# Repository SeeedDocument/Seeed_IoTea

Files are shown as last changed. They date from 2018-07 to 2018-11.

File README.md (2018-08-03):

# Seeed_IoTea

IoTea的节点代码和PCB图。
<a href="https://cn1.loriot.io/apps/websocket.html?token=vnwDBQAAAA1jbjEubG9yaW90LmlvliKTqUfFMlIiSug0jy9a2A==">点我查看原始数据。</a>

## 主要器材清单

### 网关

- <a href="https://www.seeedstudio.com/LoRa-LoRaWAN-Gateway-868MHz-Kit-with-Raspberry-Pi-3-p-2823.html">LoRa LoRaWAN Gateway - 868MHz Kit with Raspberry Pi 3</a>
- <a href="https://www.seeedstudio.com/Raspberry-Pi-Ultimate-Cooling-Dual-Fan-p-2926.html">Raspberry Pi Ultimate Cooling Dual Fan</a>

### 节点

- <a href="https://www.seeedstudio.com/s/Seeeduino-LoRaWAN-p-2780.html">Seeeduino LoRaWAN</a>
- <a href="https://www.seeedstudio.com/s/Grove-Temp%26Humi%26Barometer-Sensor-(BME280)-p-2653.html">BME 280 空气温湿度传感器</a>
- <a href="https://www.seeedstudio.com/s/Grove-Dust-Sensor%EF%BC%88PPD42NS%EF%BC%89-p-1050.html">Dust sensor</a>
- <a href="https://www.seeedstudio.com/s/Grove-Carbon-Dioxide-Sensor(MH-Z16)-p-1863.html">CO2 sensor</a>
- <a href="https://www.seeedstudio.com/s/Grove-Oxygen-Sensor(ME2-O2-%D0%A420)-p-1541.html">O2 sensor</a>
- <a href="https://www.seeedstudio.com/s/Grove-Digital-Light-Sensor-p-1281.html">Digital Light Sensor</a>
- <a href="https://www.seeedstudio.com/s/Soil-Moisture-%26-Temperature-Sensor-p-1356.html">Soil Moisture & Temperature Sensor</a>

# 代码部分：
## 1. 数据格式

节点向网关上传的数据为：

```c
unsigned char Lora_data[15] = {0,1,2,3,,4,5,6,7,8,9,10,11,12,13,14};
```

各项数据含义：

- **Lora_data[0]**：空气温度，摄氏度
- **Lora_data[1]**：空气湿度，百分比
- **Lora_data[2]**：海拔高度高8位，米
- **Lora_data[3]**：海拔高度低8位
- **Lora_data[4]**：CO2浓度高8位
- **Lora_data[5]**：CO2浓度低8位
- **Lora_data[6]**：灰尘浓度高8位
- **Lora_data[7]**：灰尘浓度低8位
- **Lora_data[8]**：光照强度高8位
- **Lora_data[9]**：光照强度低8位
- **Lora_data[10]**：氧气含量，单位为千分之一
- **Lora_data[11]**：土壤温度，摄氏度
- **Lora_data[12]**：土壤湿度，百分比
- **Lora_data[13]**：电池电压，单位为0.1V
- **Lora_data[14]**：错误代码

错误代码含义：

```
Lora_data[14] = [bit7, bit6, bit5, bit4, bit3, bit2, bit1, bit0]
```
- bit0：1 为 BME 280 空气温湿度传感器错误
- bit1：1 为 CO2 传感器错误
- bit2：1 为灰尘传感器错误
- bit3：1 为 Digital Light Sensor 错误
- bit4：1 为氧气传感器数据错误
- bit5：1 为土壤温湿度传感器错误
- bit6：保留
- bit7：保留

另外本文件夹内有错误代码转换器：Error_code_transform.exe ，可以打开这个.exe文件并输入十六进制的错误代码，然后就得到了传感器错误类型。

## 2. 参数调节

### 1. 数据发送运行周期

```c
// seeedtea.ino
#define interval_time 600			//间隔时间，秒
```
更改此参数可改变数据发送间隔。在每次循环中，数据采集需耗时约 1 分钟，不建议将此值改为60秒以内。值越大，系统运行越省电。

### 2. 灰尘传感器预热时间

```c
// seeedtea.ino
#define Preheat_time 30000			//Dust Sensor预热时间，单位 ms
//Dust_other.cpp
#define sampletime_ms 30000		//采样时间30s;
```
灰尘传感器需要一定预热时间来让传感器内的空气流动起来。

### 3. 电压系数

```c
//POWER_Ctrl.cpp
#define Battery_coefficient 0.159864	//ADC读数乘以这个系数就是电池电压
#define Solar_coefficient   0.22559	  //ADC读数乘以这个系数就是太阳能电压
```

### 4. 风扇参数调节

```c
//POWER_Ctrl.cpp
#define Fan_start_temp 45     //风扇开始运行温度
#define Fan_start_light 500   //风扇开始运行光照强度
```

### 5. 氧气传感器参数

```c
//Oxygen.cpp
#define O2_percentage 208.00  //初始化时会按照这个值校准氧气传感器，单位为千分之一
```

### 6. 宏开关，注释后会停止相应模块工作

```c
// seeedtea.ino
#define LORA_RUN      //注释后lora初始化和数据发送停止
#define SENSOR_RUN    //注释后外部传感器停止工作

//POWER_Ctrl.cpp
#define FAN_ON        //使用一个固定的电池电压代替采集到的电池电压，解除电压对风扇的判断
                      //测试使用。实际应用需注释掉
/******* DS18B20 模式控制 **********************/
#define Slower_Mode		//慢速模式获取温度。注释掉即为快速模式
```

### 7. 引脚定义

D2：接 LED 指示灯和外部复位单片机

I2C：SCL 和 SDA

```c
//Dust_other.h
#define Dust_pin 3

//CO2.cpp
#define CO2_serial Serial1    //CO2 传感器使用D0和D1硬件串口

//seeedtea.ino
#define dataPin 6   //土壤水分和温度传感器数据引脚
#define clockPin 7  //土壤水分和温度传感器时钟引脚

//POWER_Ctrl.h
#define DS18B20_pin 8   //板载温度传感器
#define Fan_pin 9       //风扇引脚
#define Air_CtrlPin 10  //空气传感器控制引脚
#define Soil_CtrlPin 11 //土壤传感器控制引脚
#define Battery_pin A2  //电池电压采集引脚
#define Solar_pin A3    //太阳能电压采集引脚

//Oxygen.h
#define O2_pin A1
```

### 8. 看门狗定时器

看门狗定时器用于监测系统运行状态，当系统运行异常时会复位单片机，从而使其可以长期不间断运行。

需要引用的库：

- Adafruit_SleepyDog.h            已经添加进项目中
- Adafruit_ASFcore-master.zip     打包放在项目文件夹中，需要手动添加进Arduino IDE中

#### 相关函数：

##### 1. 使能看门狗

```c
int WatchdogSAMD::enable(int maxPeriodMS, bool isForSleep)
```
输入参数：
- int maxPeriodMS：等待时间，单位毫秒。超时会复位。最大允许16000毫秒。

返回值：
- int类型，返回实际等待时间

##### 2. 复位看门狗

```c
void WatchdogSAMD::reset()
```

输入参数：无

输出参数：无

调用该函数来复位看门狗定时器，简称“喂狗”。超出等待时间未复位就会使单片机重启。

##### 3. 停止看门狗

```c
void WatchdogSAMD::disable()
```

停止看门狗定时器。

## 3. 传感器详细信息

### 1.	Temp&Humi&Barometer Sensor

供电：5Vor3.3V

参数范围：温度-40-85℃ 湿度0%-100% 气压300-100hPa

IIC通信，地址0X76，

相关函数：bme280.getTemperature(), bme280.getHumidity(), bme280.getPressure()

Lora_data[0]： 温度 Lora_data[1]： 湿度

Lora_data[2]：高8位Lora_data[3]：低8位 气压

### 2.	Dust Sensor（PPD42NS）

供电：5V 单位：pcs/L或pcs/0.01cf

相关函数：Dust_value = Dust_concentration()

Lora_data[6]：高8位  Lora_data[7]：低8位 灰尘

### 3.	Carbon Dioxide Sensor(MH-Z16)

供电：4.5V-6V 范围：0-2000ppm

UART通信

相关函数：unsigned int CO2_dataRecieve(void)

Lora_data[4]：高8位   Lora_data[5]：低8位  CO2浓度

### 4.	Digital Light Sensor

供电：5V 范围0.1-40000LUX

IIC通信，地址 0X29,

相关函数：TSL2561.readVisibleLux()

Lora_data[8]：高8位   Lora_data[9]：低8位  光照

### 5.	Oxygen Sensor(ME2-O2-Ф20)

供电：3.3V/5V 范围：0-25%

读模拟值

int O2_value()

Lora_data[10] 氧气浓度（通过该函数获得的值要除以10，得到百分比）

### 6.	Soil Moisture & Temperature Sensor

供电：3.3V 范围：温度-40-+123.8℃ 湿度0-100%

sht1x.readTemperatureC() sht1x.readTemperatureF() sht1x.readHumidity()

Lora_data[11] 土壤温度 Lora_data[12] 土壤湿度

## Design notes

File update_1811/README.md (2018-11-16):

# Seeed IoTea LoRa Solution

*Internet+* is a popular concept at this moment. This time we tried the Internet plus agriculture to make tea garden grows out the Internet Tea.

## Things used in this project

### Hardware components

- LoRa/LoRaWAN Gateway Kit
- Grove - Barometer Sensor(BME280)
- Grove - Dust Sensor
- Grove - Gas Sensor(O₂)
- Grove - CO2 Sensor
- Grove - Digital Light Sensor
- Soil Moisture & Temperature Sensor
- USB Camera
 
### Software apps and online services

- Microsoft Visual Studio 2015

## Story

On Mengding Mountain northeast of Ya’an, Sichuan, the mountain ridge runs west to east in a sea of green. This is a most familiar sight for 36-year-old Deng, one of the very few Mengding tea makers of his generation, with a plantation of 50mu (=3.3 hectares) situated at 1100m above sea level. Deng comes from a family of tea makers, but carrying on the family legacy is not an easy task. “Our teas are grown at high altitude in an organic environment to ensure its excellent quality. But at the same time, the growth density is low, cost is high and budding is uneven, making tea hard to harvest. That’s why high-mountain teas are normally small harvests and their values are not reflected on the market.”For the past two years, Deng has been trying to raise consumer awareness of high-mountain tea to promote their value. And when he met Fan, who was looking for a plantation to implement Seeed’s IoTea technology, a perfect match for a solution was made.

### Hardware Connection

The hardware of this project can be splitted to 4 parts: Power, Sensors, Node and Gateway. Following article will show you how to complete it step by step.

**Power Part**

Power Part mainly contains a Solar Panel and a Lithium Battery, if you just build this project for demonstration, you can ignore them. Or you can follow [Previous tutorial](https://project.seeedstudio.com/SeeedStudio/seeed-lora-iotea-solution-b5ee95) to install node power.

**Sensor Part**

In Sensor Part, because of the many of sensors, we used a weather station, and also made a Acrylic bracket to install them.

Sensor Part

As you see in the picture above, Digital Light Sensor always on the top, so that it can collect lighting infomation. The sensors that will generate heat are installed in middle of the Acrylic bracket, such as O2 Sensor, Dust Sensor and CO2 Sensor. At last, Temperature and Humidity Sensor on the bottom of Acrylic bracket.

Besides, Soil Temperature and Humidity Sensor is installed alone in the soil.

**Node Part**

Node Part

Node Part is a Seeeduino LoRaWan which installed in a Waterproof Box, it connect to power and sensors via Water Joints. Among them, Dust Sensor connect to LoRaWan's digital pin D3, CO2 Sensor connect to pin D4 & D5, Soil Sensor connect to pin D6 & D7, O2 Sensor connect to analog pin A1 and Light Sensor & Barometer Sensor connect to I2C port.

*NOTE: A 10k Resistor should be added between Soil Sensor's Blue(Data) cable and Red(Vcc) cable.*

Seeeduino LoRaWan collect sensors value once in a while, and send them to Gateway via LoRa. The data format like below:

    {
    	[0],	/* Air tempreature(℃)						*/
    	[1],	/* Air humidity(%)							*/
    	[2],	/* Altitude(m) high byte					*/
    	[3],	/* Altitude(m) low byte						*/
    	[4],	/* CO2 concentration(PPM) high byte			*/
    	[5],	/* CO2 concentration(PPM) low byte			*/
    	[6],	/* Dust concentration(pcs/0.01cf) high byte	*/
    	[7],	/* Dust concentration(pcs/0.01cf) low byte	*/
    	[8],	/* Light intensity(lux) high byte			*/
    	[9],	/* Light intensity(lux) low byte			*/
    	[10],	/* O2 concentration(%)						*/
    	[11],	/* Soil temperature(℃)						*/
    	[12],	/* Soil humidity(%)							*/
    	[13],	/* Battery voltage(V)						*/
    	[14]	/* Sensor error code						*/
    }

Each bit in Sensor Error Code byte has a difference meaning, just like below:

    {
    	bit0: 1;		/* Barometer Sensor Error			*/
    	bit1: 1;		/* CO2 Sensor Error					*/
		bit2: 1;		/* Dust Sensor Error				*/
		bit3: 1;		/* Light Sensor Error				*/
		bit4: 1;		/* O2 Sensor Error					*/
		bit5: 1;		/* Soil Sensor Error				*/
		reserved: 2;	/* Reserved							*/
    }

**Gateway Part**

Gateway Part

Gateway Part is a Raspberry Pi which plugged Gateway module RHF0M301–868 and PRI 2 Bridge RHF4T002, it installed in a Waterproof Box and connect to power & USB Camera via Water Joints. Because it use specialized firmware, please follow [Seeed Wiki](http://wiki.seeedstudio.com/LoRa_LoRaWan_Gateway_Kit/) to configure it.

### Software Programming

As Hardware Connection, Software Programming also can be splitted, it can be splitted to 3 parts: Node, Gateway and Website.

**Node Part**

Most of drivers that Node Part required are already contained in `origin_driver` folder. The libraries following down need to be installed manually: 

- [Adafruit_ASFcore](https://github.com/adafruit/Adafruit_ASFcore)

Because the project is complicated, we recommend you use Microsoft Visual Studio instead of Arduino IDE. A plugin called Visual Micro can help you biuld an Arduino project by using Visual Studio, click [here](https://www.visualmicro.com/) for more information.

For better readability and maintainability, we use Object-Oriented Programming this time. The class diagram of this project looks like below:

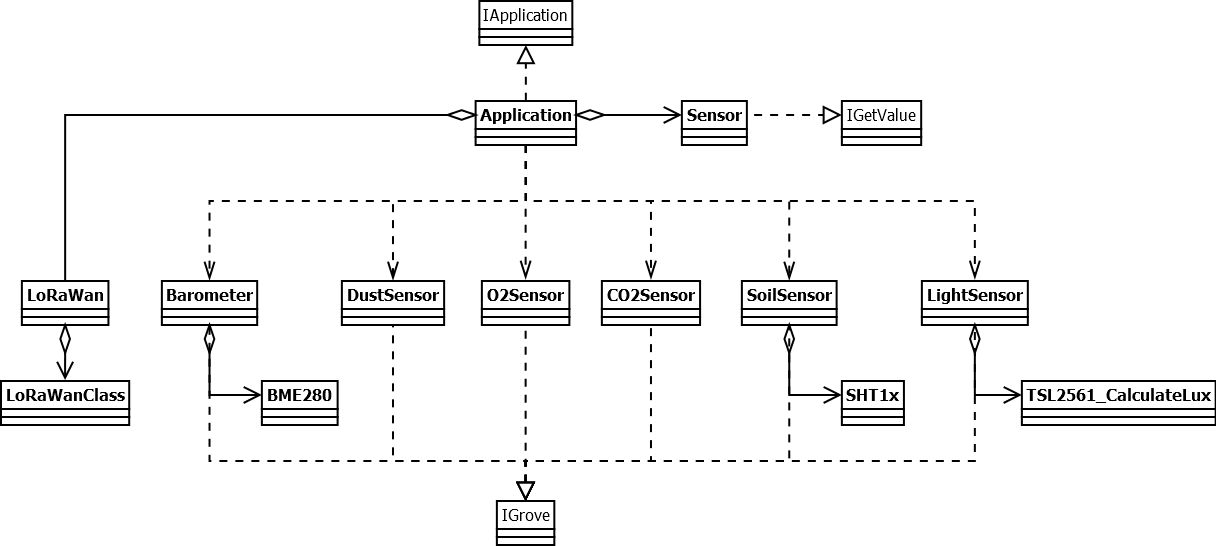
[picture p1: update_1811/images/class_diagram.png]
class diagram


For those sensors already have OOP driver, we repacked it to adapt this project, for others, we rewrote their drivers by using OOP. The Sensor class in middleware layer is used to unify interfaces of real sensors, for example, a barometer sensor can collect temperature, humidity and altitude at the same time, so it has 3 interfaces to acquire temperature, humidity and altitude. But they have difference method name, which will make the program of acquiring sensors value more complicated, just like this:

    barometer->getTemperature();
    barometer->getHumidity();
    barometer->getAltitude();
    // ...
    another_sensor->getSomeValue();
    // ...

But using OOP, it looks like this:

    for (auto i = 0; i < SENSORS_COUNT; i++) {
    	sensors[i]->getValue();
    }

We also packed an Application class, it implement IApplication interface, the setup() and loop() method in IoTea.ino can call setup() and loop() method in Application object.

*NOTE: USB Serial is used to debug ONLY. After debugging, please comment it's initialize code in setup() method.*

**Gateway Part**

Gateway Part's Python program in home folder is used to take photos and upload them to Amazon S3 Server every hour. Before you use it, configure your AWS by following steps. Firstly, install AWS SDK and AWS CLI to gateway by using commands: 

	pip install boto3
    pip install awscli --upgrade --user

And then, enter AWS CLI install folder and run AWS CLI:

    cd ~/.local/bin && ./aws configure

Configure your AWS Access Key ID, AWS Secret Access ID and Default region name. After that, you are ready to take and upload photos to AWS S3 Server, photo.py looks like:

    #!/usr/bin/python
    
    import boto3
    import os
    import time
    
    # Create an S3 client
    s3 = boto3.client('s3')
    bucket_name = 'static.seeed.cc'
    
    while True:
    	try:
    		localtime = time.localtime(time.time())
    		if int(time.strftime('%M', localtime)) != 0:
    			continue
    		
    		year = time.strftime('%Y', localtime)
    		season = int(time.strftime('%m', localtime)) % 4 + 1
    		filename = time.strftime('%Y%m%d-%H0000', localtime) + '.jpg'
    		
    		# Take photo
    		os.system("fswebcam --no-banner -r 1920x1080 {}".format(filename))
    		
    		upload_path = 'files/iotea/{}s{}/{}'.format(year, season, filename)
    		
    		# Uploads the given file using a managed uploader, which will split up large
    		# files automatically and upload parts in parallel.
    		s3.upload_file(filename, bucket_name, upload_path)
    		print('Uploaded file to {}'.format(upload_path))
    		
    		# Remove local file
    		os.remove(filename)
    		print('Deleted local file {}'.format(filename))
    	except:
    		continue
    	finally:
    		time.sleep(60)

If you don't like to upload your photos, you can comment codes about S3 above. For run this program after booting gateway every time, you can install a Desktop to your Raspberry Pi by using these commands:

    sudo apt-get update
    sudo apt-get install xorg
    sudo apt-get install lxde openbox
    sudo apt-get install pix-icons pix-plym-splash pixel-wallpaper
    sudo apt-get install raspberrypi-ui-mods
    sudo reboot

And then, add `@lxterminal -e python /home/rxhf/photo.py` to file `/home/rxhf/.config/lxsession/LXDE-pi`, let it looks like this:

    @lxpanel --profile LXDE-pi
    @pcmanfm --desktop --profile LXDE-pi
    @lxterminal -e python /home/rxhf/photo.py
    @xscreensaver -no-splash
    @point-rpi

**Website**

You can configure a web site by following [here](https://github.com/SeeedDocument/iotea-hb/blob/master/iotea.md), or using other framework.

## Operation

You can visit our websites to view real-time data:

- [In Yaan](https://iotea.seeed.cc/)
- [Demonstration](https://iotea-hb.seeed.cc/)

[Video](https://www.youtube.com/watch?v=4df5kaaKa6I&feature=youtu.be)

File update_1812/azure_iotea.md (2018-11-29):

# Seeed IoTea LoRa Solution (with Azure, Update 1812)

Microsoft Azure is a Cloud Service which provide more powerful and stable computing power, this time we tired send our IoTea data to it.

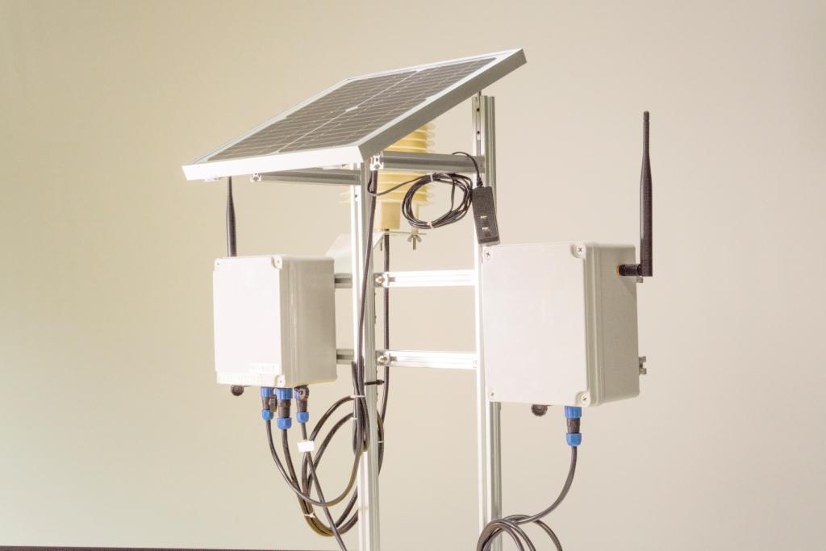
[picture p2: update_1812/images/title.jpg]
Title


## Things used in this project
### Hardware components
- Seeed LoRa LoRaWAN Gateway - 868MHz Kit with Raspberry Pi 3
- Seeed Grove - Temp&Humi&Barometer Sensor (BME280)
- Seeed Grove - Dust Sensor（PPD42NS）
- Seeed Grove - Oxygen Sensor(ME2-O2-Ф20)
- Seeed Grove - Carbon Dioxide Sensor(MH-Z16)
- Seeed Grove - Digital Light Sensor
- Seeed Soil Moisture & Temperature Sensor
- USB Camera
### Software apps and online services
- Microsoft Visual Studio 2015
- Microsoft Azure

## Story
On Mengding Mountain northeast of Ya’an, Sichuan, the mountain ridge runs west to east in a sea of green. This is a most familiar sight for 36-year-old Deng, one of the very few Mengding tea makers of his generation, with a plantation of 50mu (=3.3 hectares) situated at 1100m above sea level. Deng comes from a family of tea makers, but carrying on the family legacy is not an easy task. “Our teas are grown at high altitude in an organic environment to ensure its excellent quality. But at the same time, the growth density is low, cost is high and budding is uneven, making tea hard to harvest. That’s why high-mountain teas are normally small harvests and their values are not reflected on the market.”For the past two years, Deng has been trying to raise consumer awareness of high-mountain tea to promote their value. And when he met Fan, who was looking for a plantation to implement Seeed’s IoTea technology, a perfect match for a solution was made.

### Hardware Connection
Please follow [Previous Tutorial](https://project.seeedstudio.com/SeeedStudio/seeed-iotea-lora-solution-update-1811-860035) to connect your hardware.

### Cloud Configure
**Step 1. Create Resource Group**

Click [here](https://portal.azure.com) to login Microsoft Azure. And then, enter Resource groups in list on the left of dashboard, click Add to add a Resource Group.

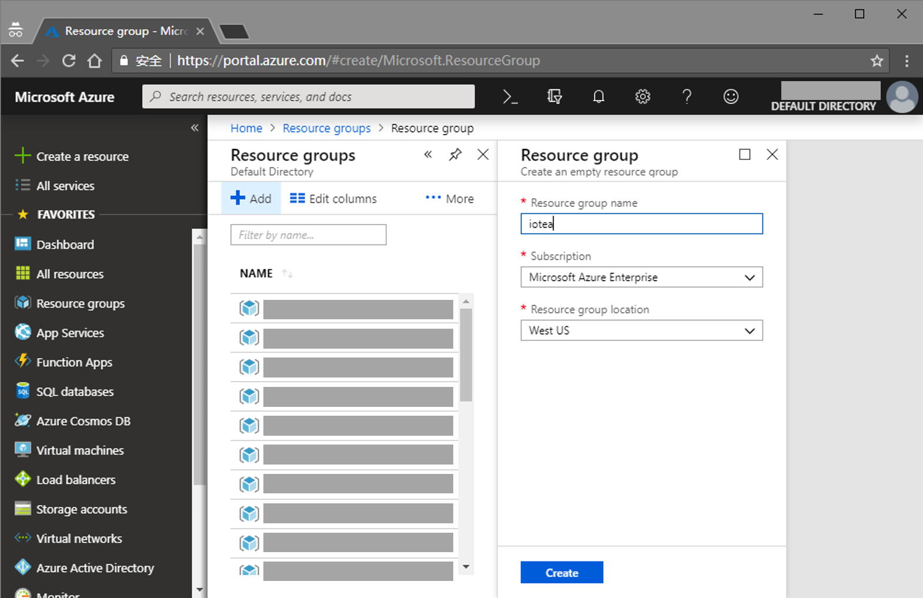
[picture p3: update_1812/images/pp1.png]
Add Resource Group


A Resource Group is used to manage all resources in project, after using cloud resources, delete resource group to delete all resources to avoid charges. In opened page, fill Resource group name(such as iotea), choose Subscription and Resource group location if needed, click Create to create a Resource Group. 

**Step 2. Create Iot Hub**

Now you can create a cloud resource, click Create a resouce on the left, choose Internet of Things - Iot Hub, it will open a new page.

In Basics tab, choose the Resource Group you just created, and fill Iot Hub Name(such as iotea), choose Subscription and Region if needed, and then turn to Size and scle tab.

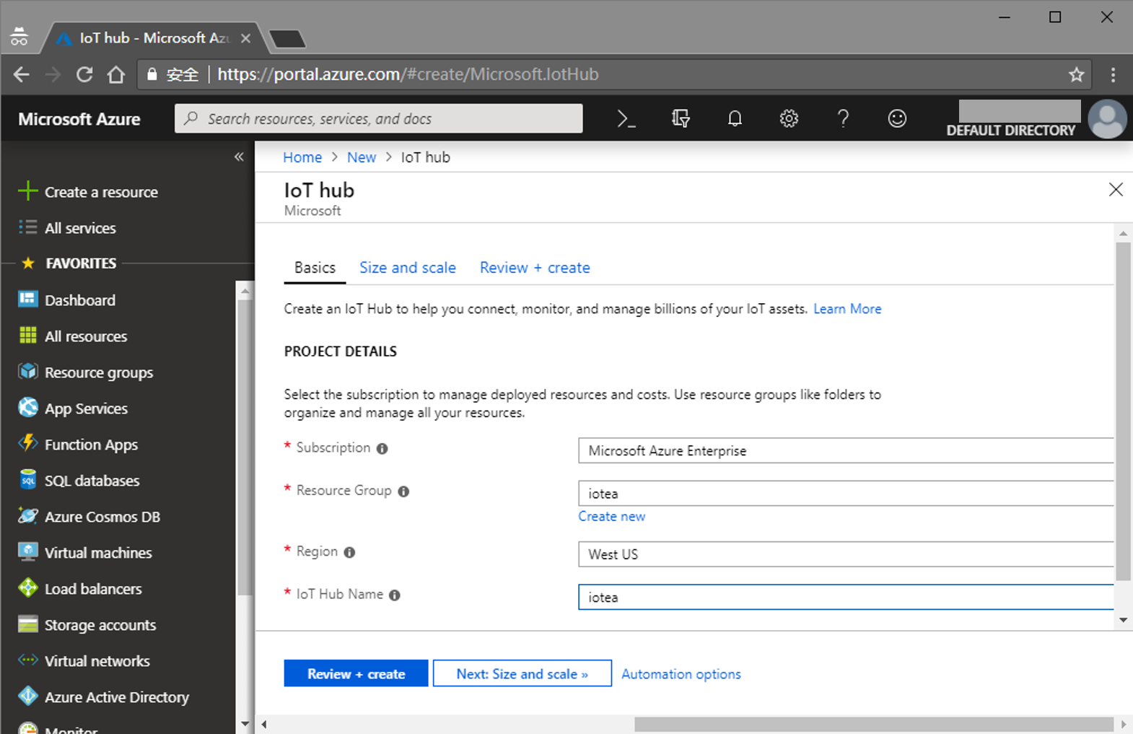
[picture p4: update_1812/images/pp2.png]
Iot Hub Basics


In Size and scale tab, choose F1: Free tier or B1: Basic tier in Pricing and scale tier combo, Basic Tier will take 10.00 USD per month. Finally, turn to Review + create tab check you input and click Create to create a Iot Hub.

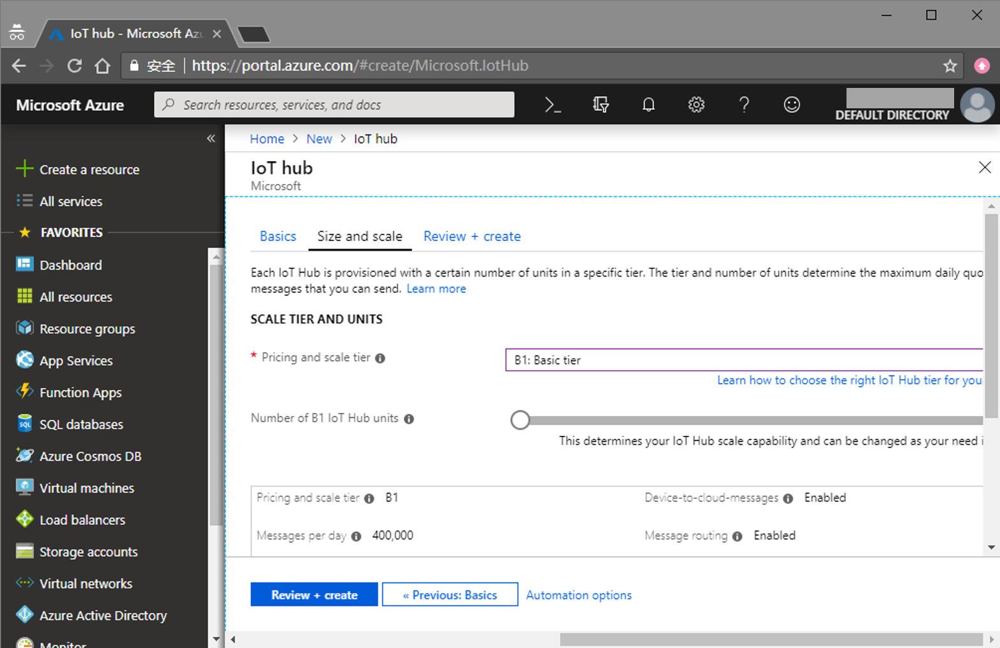
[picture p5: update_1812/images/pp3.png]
Iot Hub Size and scale


**Step 3. Configure LORIOT**

Enter the Iot Hub you just create, click Shared access policies - device, copy the Primary key in page on the right.

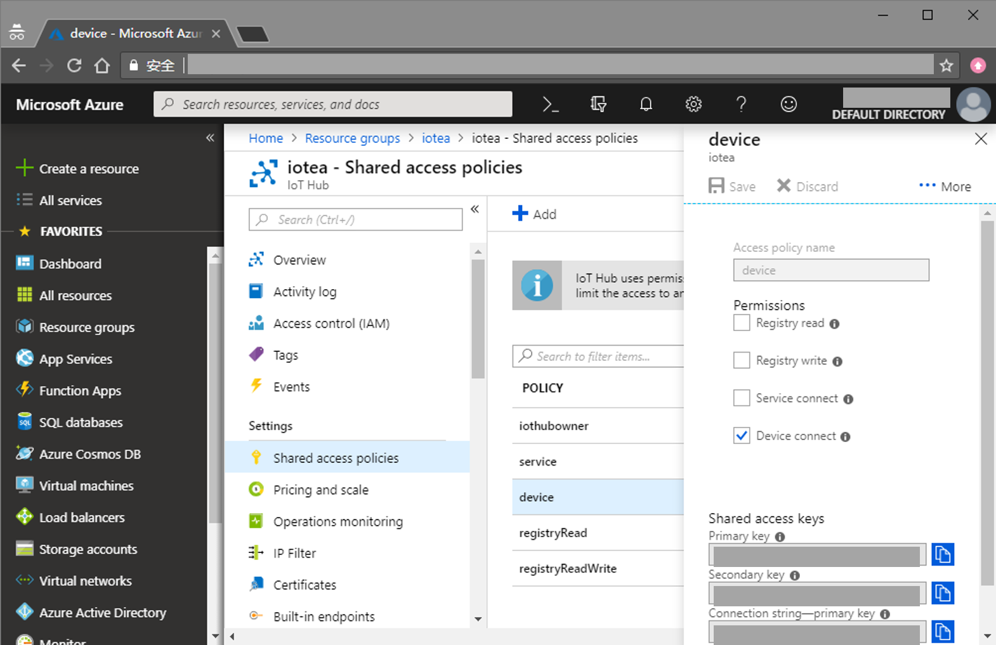
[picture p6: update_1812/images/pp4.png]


Open a new brower window(or tab), login your LORIOT Control Panel, turn to Application - SampleApp, click Data output in Control group - Change. In Change output type group, choose Azure Iot Hub, fill your Iot Hub Name and Primary key, and click Confirm change button on the bottom.

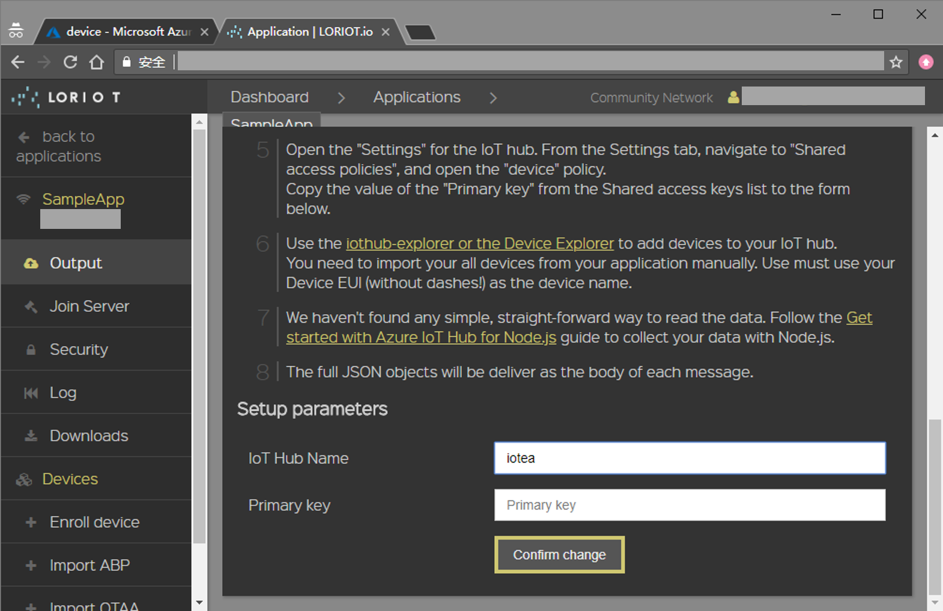
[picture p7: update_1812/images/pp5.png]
LORIOT Change output type


**Step 4. Add Iot device**

Click Devices in list on the left in LORIOT, copy your Device EUI.

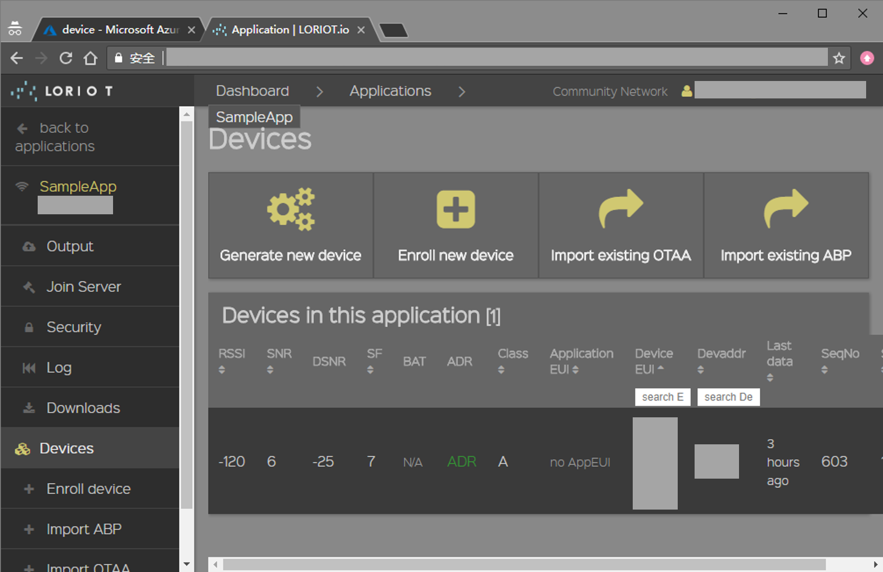
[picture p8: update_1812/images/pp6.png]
LORIOT Devices


Back to Azure Iot Hub, click Iot devices in the list on the left of Iot Hub. Click Add, fill Device EUI to Device ID in opened page.

*IMPORTANT: DELETE ALL SEPRATOR IN DEVICE EUI, let it looks like 1122334455667788.*

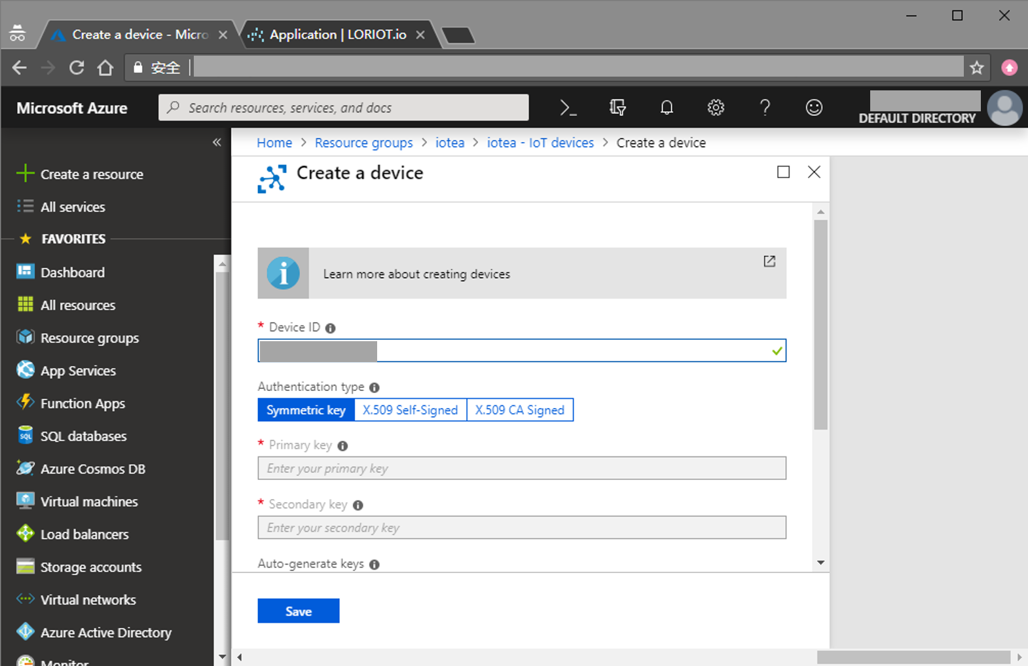
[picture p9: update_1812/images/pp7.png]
Iot Hub Create a device


Click Save, all done.

**Step 5. Receive D2C(Device to Cloud) Messages**

You can follow [Microsoft Docs](https://docs.microsoft.com/en-us/azure/iot-hub/quickstart-send-telemetry-dotnet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) to read D2C Messages.

### Software Programming

Software Programming is splitted to 3 parts: Node, Gateway and Website, please follow [Previous Tutorial](https://project.seeedstudio.com/SeeedStudio/seeed-iotea-lora-solution-update-1811-860035) to program Node Part and Gateway Part. Steps 1 through 8 of the Website Part are also same as [Previous Tutorial](https://project.seeedstudio.com/SeeedStudio/seeed-iotea-lora-solution-update-1811-860035).

If you already configured Microsoft Azure, open a terminal, enter your website's root folder, activate virtual enviroment:

	cd ~/iotea-hb
	source bin/activate

install Azure Event Hub module via pip, and create a new .py file(such as iothub_recv.py):

	pip install azure-eventhub
	touch iothub_recv.py

and then write codes following down to it:

	# --------------------------------------------------------------------------------------------
	# Copyright (c) Microsoft Corporation. All rights reserved.
	# Licensed under the MIT License. See License.txt in the project root for license information.
	# --------------------------------------------------------------------------------------------
	
	from azure import eventhub
	from azure.eventhub import EventData, EventHubClient, Offset
	
	import logging
	logger = logging.getLogger('azure.eventhub')
	
	import db, json, time, datetime

	def get_time():
		cntime = datetime.datetime.now() + datetime.timedelta(hours = +8)
		
		date = cntime.strftime('%Y-{}-{}').format(cntime.strftime('%m').zfill(2), cntime.strftime('%d').zfill(2))
		
		hour = cntime.strftime('%H').zfill(2)
		minute = cntime.strftime('%M').zfill(2)
		second = cntime.strftime('%S').zfill(2)
		
		return [date, hour, minute, second]

	def get_iothub_data():
		list = ['0'] * 11
		
		client = EventHubClient.from_iothub_connection_string('<your_connection_string>', debug=True)
		receiver = client.add_receiver("$default", "3", operation='/messages/events', offset = Offset(datetime.datetime.utcnow()))
		
		try:
			client.run()
			eh_info = client.get_eventhub_info()
			print(eh_info)
			
			received = receiver.receive(timeout=5)
			print(received)
			
			for item in received: 
				message = json.loads(str(item.message))
				print(message)
				
				if 'data' in message:
					data = message['data']
					
					air_temp = str(int(data[0:2], 16))
					air_hum = str(int(data[2:4], 16))
					pressure = str(int((data[4:8]), 16))
					co2 = str(int(data[8:12], 16))
					dust = str(int(data[12:16], 16))
					illumination = str(int(data[16:20], 16))
					o2 = str(round(int(data[20:22], 16) / 10, 1))
					soil_temp = str(int(data[22:24], 16))
					soil_hum = str(int(data[24:26], 16))
					voltage = str(round(int(data[26:28], 16) / int('ff', 16) * 5, 1))
					error = str(int(data[28:], 16))
					
					list = [air_temp, air_hum, pressure, co2, dust, illumination, o2, soil_temp, soil_hum, voltage, error]
		
		finally:
			client.stop()
		
		return list

	while True:
		list = get_time() + get_iothub_data()
		db.insert(list)
		print(list)

Before you running the program, change your connection string in 

	client = EventHubClient.from_iothub_connection_string('<your_connection_string>', debug=True)

you can get your connection string by clicking Shared access policies - iotowner in Iot Hub, the Connection string-primnary key in opened page is the connection string.

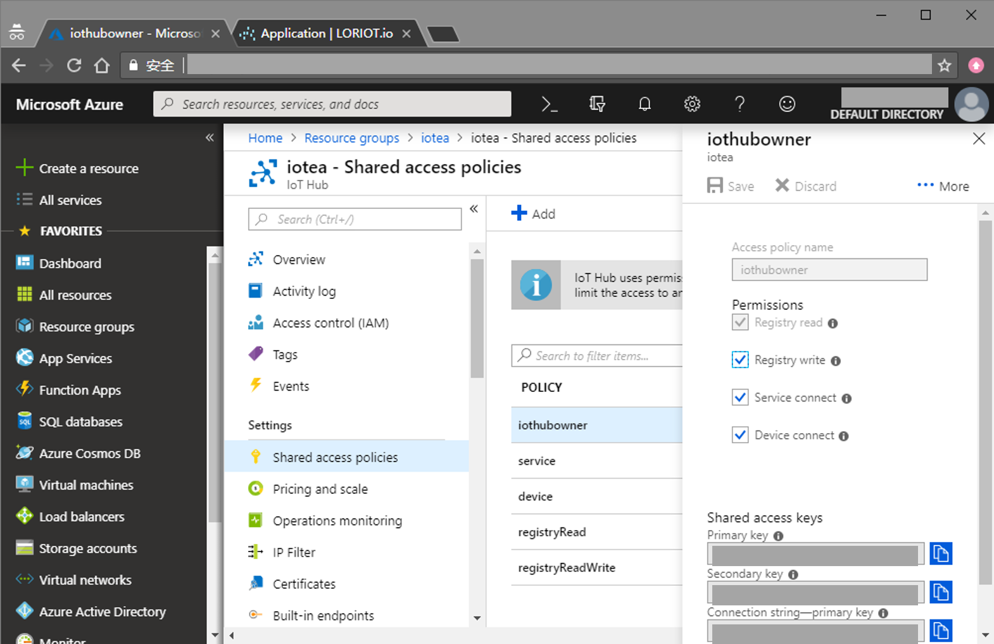
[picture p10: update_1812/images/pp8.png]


After that, you can start the program:

	gunicorn iothub_recv:app

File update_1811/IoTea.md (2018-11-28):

# Seeed IoTea LoRa Solution

*Internet+* is a popular concept now. This time we tried the Internet plus agriculture to make tea garden grows out the Internet Tea.

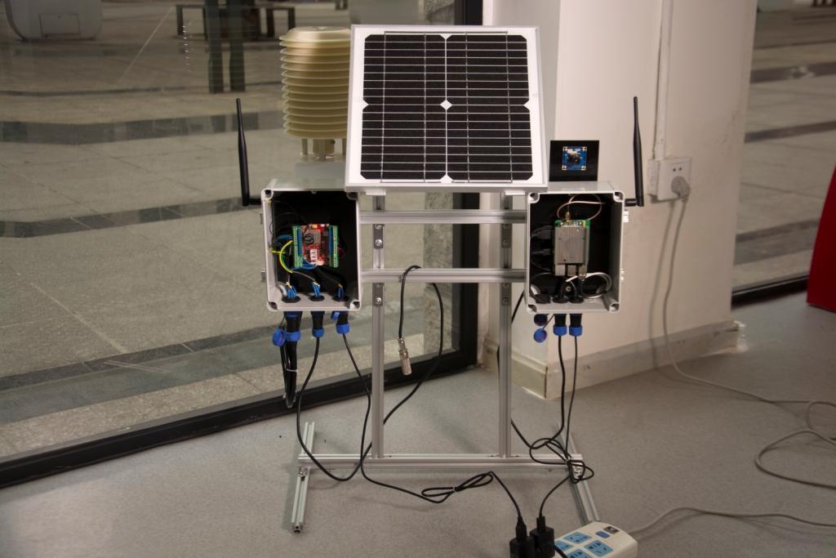
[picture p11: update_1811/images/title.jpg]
Seeed IoTea LoRa Solution


## Things used in this project

### Hardware components

- LoRa/LoRaWAN Gateway Kit
- Grove - Barometer Sensor(BME280)
- Grove - Dust Sensor
- Grove - Gas Sensor(O₂)
- Grove - CO2 Sensor 
- Grove - Digital Light Sensor
- Soil Moisture & Temperature Sensor
- USB Camera
 
### Software apps and online services

- Microsoft Visual Studio 2015

## Story

On Mengding Mountain northeast of Ya’an, Sichuan, the mountain ridge runs west to east in a sea of green. This is a most familiar sight for 36-year-old Deng, one of the very few Mengding tea makers of his generation, with a plantation of 50mu (=3.3 hectares) situated at 1100m above sea level. Deng comes from a family of tea makers, but carrying on the family legacy is not an easy task. “Our teas are grown at high altitude in an organic environment to ensure its excellent quality. But at the same time, the growth density is low, cost is high and budding is uneven, making tea hard to harvest. That’s why high-mountain teas are normally small harvests and their values are not reflected on the market.”For the past two years, Deng has been trying to raise consumer awareness of high-mountain tea to promote their value. And when he met Fan, who was looking for a plantation to implement Seeed’s IoTea technology, a perfect match for a solution was made.

### Hardware Connection

The hardware of this project can be splitted to 4 parts: Power, Sensors, Node and Gateway. Following article will show you how to complete it step by step.

**Power Part**

Power Part mainly contains a Solar Panel and a Lithium Battery, if you just build this project for demonstration, you can ignore them. Or you can follow [Previous tutorial](https://project.seeedstudio.com/SeeedStudio/seeed-lora-iotea-solution-b5ee95) to install node power.

**Sensor Part**

In Sensor Part, because of the many of sensors, we used a weather station, and also made a Acrylic bracket to install them.

Sensor Part

As you see in the picture above, Digital Light Sensor always on the top, so that it can collect lighting infomation. The sensors that will generate heat are installed in middle of the Acrylic bracket, such as O2 Sensor, Dust Sensor and CO2 Sensor. At last, Temperature and Humidity Sensor on the bottom of Acrylic bracket.

Besides, Soil Temperature and Humidity Sensor is installed alone in the soil.

**Node Part**

Node Part

Node Part is a Seeeduino LoRaWan which installed in a Waterproof Box, it connect to power and sensors via Water Joints. Among them, Dust Sensor connect to LoRaWan's digital pin D3, CO2 Sensor connect to pin D4 & D5, Soil Sensor connect to pin D6 & D7, O2 Sensor connect to analog pin A1 and Light Sensor & Barometer Sensor connect to I2C port.

*NOTE: A 10k Resistor should be added between Soil Sensor's Blue(Data) cable and Red(Vcc) cable.*

Seeeduino LoRaWan collect sensors value once in a while, and send them to Gateway via LoRa. The data format like below:

    {
    	[0],	/* Air tempreature(℃)						*/
    	[1],	/* Air humidity(%)							*/
    	[2],	/* Altitude(m) high byte					*/
    	[3],	/* Altitude(m) low byte						*/
    	[4],	/* CO2 concentration(PPM) high byte			*/
    	[5],	/* CO2 concentration(PPM) low byte			*/
    	[6],	/* Dust concentration(pcs/0.01cf) high byte	*/
    	[7],	/* Dust concentration(pcs/0.01cf) low byte	*/
    	[8],	/* Light intensity(lux) high byte			*/
    	[9],	/* Light intensity(lux) low byte			*/
    	[10],	/* O2 concentration(%)						*/
    	[11],	/* Soil temperature(℃)						*/
    	[12],	/* Soil humidity(%)							*/
    	[13],	/* Battery voltage(V)						*/
    	[14]	/* Sensor error code						*/
    }

Each bit in Sensor Error Code byte has a difference meaning, just like below:

    {
    	bit0: 1;		/* Barometer Sensor Error			*/
    	bit1: 1;		/* CO2 Sensor Error					*/
		bit2: 1;		/* Dust Sensor Error				*/
		bit3: 1;		/* Light Sensor Error				*/
		bit4: 1;		/* O2 Sensor Error					*/
		bit5: 1;		/* Soil Sensor Error				*/
		reserved: 2;	/* Reserved							*/
    }

**Gateway Part**

Gateway Part

Gateway Part is a Raspberry Pi which plugged Gateway module RHF0M301–868 and PRI 2 Bridge RHF4T002, it installed in a Waterproof Box and connect to power & USB Camera via Water Joints. Because it use specialized firmware, please follow [Seeed Wiki](http://wiki.seeedstudio.com/LoRa_LoRaWan_Gateway_Kit/) to configure it.

### Software Programming

As Hardware Connection, Software Programming also can be splitted, it can be splitted to 3 parts: Node, Gateway and Website.

**Node Part**

Most of drivers that Node Part required are already contained in `origin_driver` folder. The libraries following down need to be installed manually: 

- [Adafruit_ASFcore](https://github.com/adafruit/Adafruit_ASFcore)

Because the project is complicated, we recommend you use Microsoft Visual Studio instead of Arduino IDE. A plugin called Visual Micro can help you biuld an Arduino project by using Visual Studio, click [here](https://www.visualmicro.com/) for more information.

For better readability and maintainability, we use Object-Oriented Programming this time. The class diagram of this project looks like below:

class diagram

For those sensors already have OOP driver, we repacked it to adapt this project, for others, we rewrote their drivers by using OOP. The Sensor class in middleware layer is used to unify interfaces of real sensors, for example, a barometer sensor can collect temperature, humidity and altitude at the same time, so it has 3 interfaces to acquire temperature, humidity and altitude. But they have difference method name, which will make the program of acquiring sensors value more complicated, just like this:

    barometer->getTemperature();
    barometer->getHumidity();
    barometer->getAltitude();
    // ...
    another_sensor->getSomeValue();
    // ...

But using OOP, it looks like this:

    for (auto i = 0; i < SENSORS_COUNT; i++) {
    	sensors[i]->getValue();
    }

We also packed an Application class, it implement IApplication interface, the setup() and loop() method in IoTea.ino can call setup() and loop() method in Application object.

*NOTE: USB Serial is used to debug ONLY. After debugging, please comment it's initialize code in setup() method.*

**Gateway Part**

Gateway Part's Python program in home folder is used to take photos and upload them to Amazon S3 Server every hour. Before you use it, make sure fswebcam already installed in your Raspberry Pi: 

	sudo apt-get update && sudo apt-get install fswebcam 

If you want to upload photos, configure your AWS by following steps. First, install AWS SDK and AWS CLI to your Raspberry Pi by using these commands: 

	sudo pip install boto3
    sudo pip install awscli

and then, run AWS CLI:

    sudo aws configure

Configure your AWS Access Key ID, AWS Secret Access ID and Default region name. 

If you don't like to upload your photos, you can skip AWS configuration steps and comment codes about uploading in photo.py. For running this program after booting Raspberry Pi every time, you can create a file name photo in /etc/init.d, and write the following code to it.

    #!/bin/bash
    # /etc/init.d/photo
     
    ### BEGIN INIT INFO
    # Provides: seeed_photo
    # Required-Start: $remote_fs $syslog
    # Required-Stop: $remote_fs $syslog
    # Default-Start: 2 3 4 5
    # Default-Stop: 0 1 6
    # Short-Description: photo taking initscript
    # Description: This service is used to manage photo taking
    ### END INIT INFO
     
    case "$1" in
    start)
    echo "Start taking photo"
    /home/rxhf/photo.py &
    ;;
    stop)
    echo "Stop taking photo"
    kill $(ps aux | grep -m 1 'python3 /home/rxhf/photo.py' | awk '{ print $2 }')
    ;;
    *)
    echo "Usage: service photo start|stop"
    exit 1
    ;;
    esac
    exit 0

set execution permission

	sudo chmod 777 /etc/init.d/photo
	sudo chmod 777 /home/rxhf/photo.py

and test it

	sudo /etc/init.d/photo start

If there is no problem, stop it and add it to startup application

	sudo /etc/init.d/photo stop
	sudo update-rc.d photo defaults

*NOTE: If you want to startup gateway after Raspberry Pi booting, add gateway starting codes in Seeed Wiki to /etc/rc.local, let it lokks like:*

	#!/bin/sh -e
	#
	# rc.local
	#
	# This script is executed at the end of each multiuser runlevel.
	# Make sure that the script will "exit 0" on success or any other
	# value on error.
	#
	# In order to enable or disable this script just change the execution
	# bits.
	#
	# By default this script does nothing.
	
	# Print the IP address
	_IP=$(hostname -I) || true
	if [ "$_IP" ]; then
	  printf "My IP address is %s\n" "$_IP"
	fi
	
	cd /home/rxhf/loriot/1.0.2
	sudo systemctl stop pktfwd
	sudo gwrst
	wget https://cn1.loriot.io/home/gwsw/loriot-risinghf-rhf2s008-rhf1257-SPI-0-latest.bin -O loriot-gw.bin
	chmod +x loriot-gw.bin
	./loriot-gw.bin -f -s cn1.loriot.io
	
	exit 0

**Website**

We deployed the website on CentOS7. Following steps will show you how to deploy.

Step 1. Install Python3

	sudo yum -y install epel-release
	sudo yum -y install python36

Step 2. Install Python pip and virtual enviroment

	wget https://bootstrap.pypa.io/get-pip.py
	sudo python36 get-pip.py
	sudo pip install virtualenv

Setp 3. Clone our website from GitHub

	sudo yum -y install git
	git clone https://github.com/SeeedDocument/iotea-hb.git

Step 4. Create and activate virtual enviroment

	virtualenv -p python36 iotea-hb
	cd iotea-hb
	source bin/activate

Step 5. Install dependent libraries

	pip install pymysql
	pip install dbutils
	pip install flask
	pip install websocket-client
	pip install cofigparser

Step 6. Create database

	sudo yum -y install mariadb mariabd-server
	sudo systemctl enable mariadb
	sudo systemctl start mariadb
	mysql -uroot -p

and then use iotea_hb.sql to create a table.

Step 7. Create db.ini, and write these codes to it

    [db]
    db_port = 3306
    db_user = root
    db_host = localhost
    db_pass = 
    db_name = iotea

change db.ini's path in db.py

	# in db.py
	#cf.read("/data/www/python3_iotea_hb/iotea/conf/db.ini")
	cf.read("/home/<your_username>/iotea-hb/db.ini")

Step 8. Change port in app.py and start the website: 

	# in app.py
	#app.run(debug=True, port=6000)
	app.run(debug=True, port=8080)

	# in terminal
	pip install gunicorn
	gunicorn -w 5 -b 0.0.0.0:8080 app:app

now visit 127.0.0.1:8080 in your web browser, you can see the website, but real-time data is not displayed.

Step 9. Get loriot data

Open another terminal, reenter virtual enviroment and start loriot app: 

	cd iotea-hb
	source bin/activate
	gunicorn loriot:app 

Wait for a while, you will see data displayed in website, or you can change wss in loriot.py:

	# in loriot.py
	#ws = create_connection("wss://cn1.loriot.io/app?token=vnwEuwAAAA1jbjEubG9yaW90LmlvRpscoh9Uq1L7K1zbrcBz6w==")
	ws = create_connection(<your_wss>)

## Operation

You can visit our websites to view real-time data:

- [In Yaan](https://iotea.seeed.cc/)
- [Demonstration](https://iotea-hb.seeed.cc/)

[Video](https://www.youtube.com/watch?v=4df5kaaKa6I&feature=youtu.be)

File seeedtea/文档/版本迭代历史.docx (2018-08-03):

# IoTea迭代历史

# GitHub资料：https://github.com/SeeedDocument/Seeed_IoTea

# IoTea V1.2原始数据链接：https://cn1.loriot.io/apps/websocket.html?token=vnwDBQAAAA1jbjEubG9yaW90LmlvliKTqUfFMlIiSug0jy9a2A==

# IoTea网站：https://iotea.seeed.cc/

## 1. IoTea V1.0版本

# 时间：安装于2018年5月27日，雅安蒙顶山。于2018年7月28日被V1.2版本替代。

这个版本是初始实验版本，主要用于验证整机方案可行性和测试在复杂恶劣环境下的稳定性。整机主要由“有电危险”的铁箱，木材支架和电子电路构成。电子电路中又包括太阳能供电电路、Seeeduino LoRaWAN单片机和其他传感器构成。

传感器部分：由于传感器都带有Grove接口，所以使用一个Base Shield就可以把它们都连接到Seeeduino LoRaWAN上。传感器由BME 280 空气温湿度传感器、Dust sensor、CO2 sensor、O2 sensor、Digital Light Sensor和Soil Moisture & Temperature Sensor组成。使用过程中发现光线传感器安装位置错误、Dust Sensor和CO2 Sensor功耗过高，温湿度数据异常等问题。

电源部分：计划之初打算使用两个Solar Charger Shield，两块1万毫安时的锂电池，3个2W的太阳能板对系统供电，但是由于Solar Charger Shield的转化效率过低，系统功耗过高而进行了改进。改进后使用1块20W的太阳能板供电，一个开关电源模块对电池充电，然后由Solar Charger Shield对Seeeduino进行供电。设备在山上工作时，开关电源的螺丝端子生锈导致无法充电，节点不能正常工作。由于网关所在的农户家中经常停电，导致网关不能连续工作，所以给网关增加了锂电池的辅助电源和锂电池充电器。同时也把节点的电源连接到网关的锂电池上进行供电。但是安装后仅1天，锂电池的充电器损坏，锂电池耗尽电量后系统停止工作，只能把网关和节点连接到市电上工作。

实验结果：传感器因为安装的问题存在数据异常的情况，其电源系统也因为恶劣环境的原因不能连续工作。

## 2. IoTea V1.1版本

这个版本是展示样机，同时也是新机器结构的测试机。主控板和传感器型号与V1.0相同。与上版不同的主要是网关和节点均采用塑料防水箱安装，传感器单独放在外部的百叶窗中，传感器和节点使用防水接头连接。使用铝合金型材制作了展示支架。由于是展示机，所以取消了电池等部分。

传感器：修正了Dust Sensor和O2 Sensor采集数据算法问题，Soil Moisture & Temperature Sensor使用3.3V供电。在后续测试中发现，由于Dust Sensor和CO2 Sensor的发热量较大，使BME280的温度数据偏高，湿度数据偏低。

结构：使用防水箱，防水接头和防水百叶箱制作，提升了系统的专业性和安装维护的便利性。

## 3. IoTea V1.2版本

本版本于2018年7月28日安装在蒙顶山，用于替代V1.0版本和测试新的电源系统。整机使用30W的太阳能板和专用控制器为12V蓄电池供电，控制器输出5V为单片机和传感器供电。给传感器增加了程序控制的电源开关，使功耗大大降低。

电源部分：与前两代不同，本次使用更大功率的太阳能板和更大容量的蓄电池对系统供电。电源管理由外部的太阳能—蓄电池控制器，和单片机内部的电源管理程序组成。外部的控制器可以更好地控制蓄电池的充电和放电保护，单片机的电源管理程序有效地降低了系统的功耗，增加了低电压保护功能。目前发现的缺点是选购的控制器不支持最大功率点追踪，这使得太阳能板的最大发电功率降低为标称功率的60%~70%左右。后续可以通过更换控制器解决这个问题。在实际使用中发现电源系统的电池容量和太阳能功率过于充足，后续可根据负载来适当减小太阳能功率和电池容量。没有测试过电源器件在寒冷情况下的表现，后续需要选择在结冰温度下的可靠使用的器件。

电路部分：使用打样的PCB作为传感器和单片机的转接板，代替了以前的Base Shield和洞洞板。PCB上集成了传感器电源控制，电源滤波和温控风扇，使用更可靠的端子连接防水接头，提升了维护的便利性，降低了系统功耗。供电部分使用大容量电容阵滤波，后续需要根据负载更改滤波方案来降低成本和提升电源稳定性。目前的打样PCB上，有三个钽电容是放在MOS管后方，这个设计会导致MOS管打开瞬间，电容充电导致大电流和VCC的压降。16V和21V的采样电阻忘记连接到ADC上，现在已经在原理图中更正。PCB布线中，VCC的布线还存在优化空间。可以删除POWER LED来节能。另外接线端子的孔过大，后续需减小这个孔径。

代码部分：增加了电源控制策略和温控风扇，优化了各传感器的数据采集方法，增加了错误代码回传。目前云端（Github）的版本增加了看门狗定时器，消除了传感器掉线造成单片机死循环的BUG，更改CO2 Sensor为硬件串行端口。

接线部分：全部采用防水连接器和接线端子，降低和焊接和装配的难度，增加了维护的便利性。

结构部分：更换百叶窗为更大内径的版本，使用双实心的构造隔离了发热的传感器和温湿度传感器，使温湿度传感器的数据恢复到正常水平。但该百叶窗存在漏雨的可能性，光线传感器的安装位置也不合理，后期需要进行测试来确定是否依旧使用该型号的百叶窗。在网关和节点的防水箱中加装了风扇，并在风扇前安装了纱布滤网来滤除空气中的灰尘和水珠，防止器件发生短路。

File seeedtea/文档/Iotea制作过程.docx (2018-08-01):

Iotea

## 材料清单：

网关：

1. https://www.seeedstudio.com/LoRa-LoRaWAN-Gateway-868MHz-Kit-with-Raspberry-Pi-3-p-2823.html
2. https://www.seeedstudio.com/Raspberry-Pi-Ultimate-Cooling-Dual-Fan-p-2926.html
3. SMA天线延长线

节点：

1. Seeeduino LoRaWAN: https://www.seeedstudio.com/s/Seeeduino-LoRaWAN-p-2780.html
2. BME 280: https://www.seeedstudio.com/s/Grove-Temp%26Humi%26Barometer-Sensor-(BME280)-p-2653.html
3. Dust sensor: https://www.seeedstudio.com/s/Grove-Dust-Sensor%EF%BC%88PPD42NS%EF%BC%89-p-1050.html
4. CO2 sendor: https://www.seeedstudio.com/s/Grove-Carbon-Dioxide-Sensor(MH-Z16)-p-1863.html
5. O2 sensor: https://www.seeedstudio.com/s/Grove-Oxygen-Sensor(ME2-O2-%D0%A420)-p-1541.html
6. Digital Light Sensor: https://www.seeedstudio.com/s/Grove-Digital-Light-Sensor-p-1281.html
7. Soil Moisture & Temperature Sensor: https://www.seeedstudio.com/s/Soil-Moisture-%26-Temperature-Sensor-p-1356.html

结构件：

1. 170mm x 140mm x 95mm防水盒，2个
2. 内径62mm的百叶箱1个。
3. 10W太阳能电池板
4. 2020欧标工业铝型材：

16cm x 2

40cm x 2

50cm x 1

60cm x 2

70cm x 2

5. 30mm x 3mm铝排：长30cm，2个（有加工图纸）
6. 其他配件：

M5螺帽40个

M5普通螺栓8个

M4普通螺栓、螺帽4套

M5 T型螺栓36个

型材T型连接板6个

2020任意角度角槽连接件4个

2020直角角槽连接件6个

M5顶丝16个

其他一些五金工具和M3螺栓螺帽

7. 电路部分：

洞洞板，跳线，8芯电缆，4芯电缆，2芯、4芯、9芯防水连接器和一些电路必备器件。

## What parameters do we collect?

1. Air temperature and humidity - BME280
2. Altitude - BME280
3. Soil temperature and humidity – SHT1X
4. Illumination - TSL2561
5. CO2 concentration – MH-Z16
6. O2 percentage - ME2-O2
7. Dust concentration – PPD42NS

We have one sensor can collect air Temp&Hum&pressure: BME280.

## How to transfer data to the cloud?

We use this project in the mountains. We plan to arrange multiple sets of sensors to collect this information and upload them to the cloud. So we consider using LoRaWAN gateway and nodes to complete this project. We connect the sensor to the Lora node, then transfer the data from nodes to a gateway, and finally the gateway uploads all the data to the cloud. Ok, let’s do this.

## Use the Lorawan Kit transfer data

Open the Lorawan Kit, you can find one Lorawan getway(Based on Raspberry Pi) , one Seeeduino Lorawan node and some other accessories. Follow this wiki(http://wiki.seeedstudio.com/LoRa_LoRaWan_Gateway_Kit/) to connect the gateway to the Internet and configure the nodes and gateways. Run the ABP routine on Seeeduino LoRaWAN and you will see the data sent by the node in the cloud. A free account can have one gateway and 10 nodes.

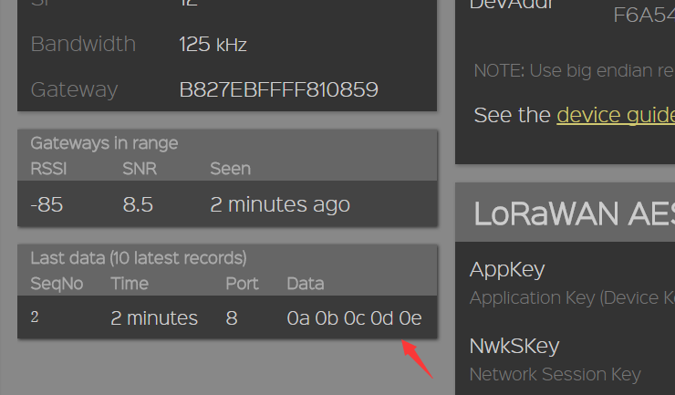
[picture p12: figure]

## Collect the sensor data

Here we have six sensors. The BME280 and TSL2561 is I2C port, the O2 sensor is analog port, and others are in digital port.

#define O2_pin A1

#define Dust_pin 3

#define CO2_TX 4

#define CO2_RX 5

#define dataPin 6 //Soil Temp&Hum sensor data pin

#define clockPin 7 //Soil Temp&Hum sensor clock pin

I defined a global array to store the data for each sensor. Since the LoRaWAN library only receives 8 bits of data, I need to split some data into high 8 bits and low 8 bits for transmission.

unsigned char Lora_data[15] = { 0, 1, 2, 3, 4, 5, 6, 7, 8, 9,10,11,12,13,14 };

Below is an index of each data:

Lora_data[0]：Air temperature

Lora_data[1]：Air humidity

Lora_data[2]：Altitude high 8-bits(reserve)

Lora_data[3]：Altitude low 8-bits(reserve)

Lora_data[4]：CO2 data high 8-bits

Lora_data[5]：CO2 data low 8-bits

Lora_data[6]：Dust data high 8-bits

Lora_data[7]：Dust data low 8-bits

Lora_data[8]：Light data high 8-bits

Lora_data[9]：Light data low 8-bits

Lora_data[10]：O2 data(thousandth)

Lora_data[11]：Soil temperature

Lora_data[12]：Soil humidity

Lora_data[13]：Battery voltage(reserve)

Lora_data[14]：Error code(reserve)

Collect and fill the sensor data into the array and use Lora_send(data_length) to send the data to the LoRaWAN gateway. Open loriot.io and find WebSocket in the Output:

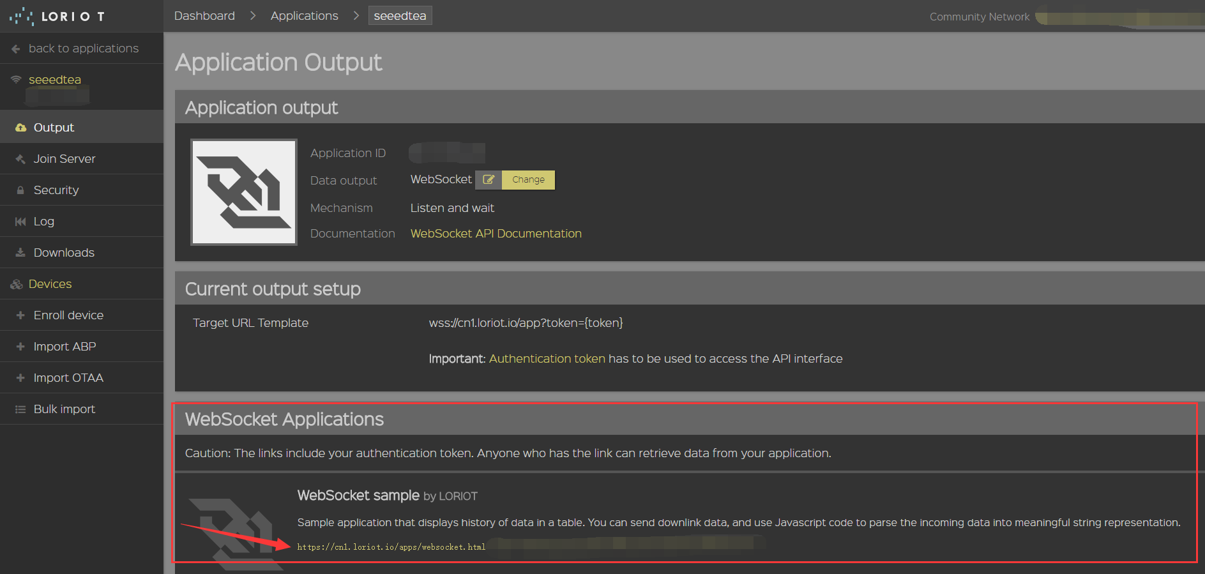
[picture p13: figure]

After clicking the WebSocket link, you can see the data shown below.

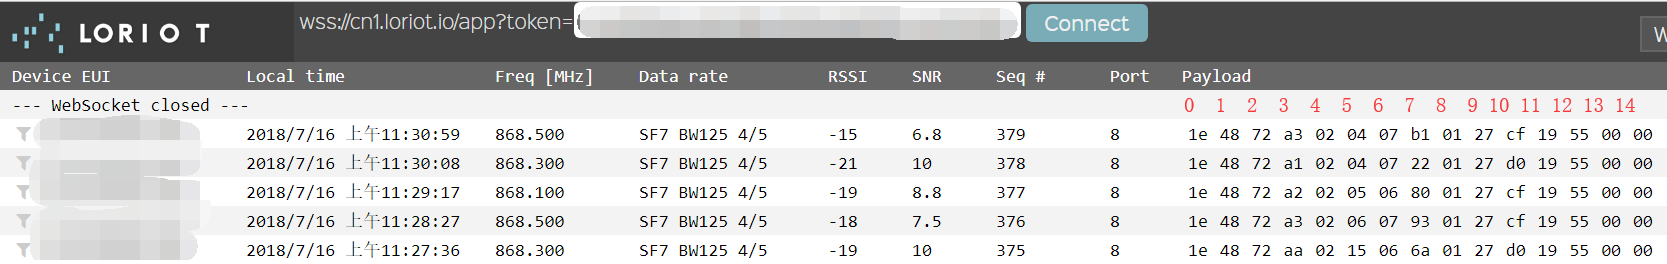
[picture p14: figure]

Device EUI: Your Seeeduino Lorawan Dev EUI.

RSSI: Received Signal Strength Indicator.

SNR: Signal Noise Ratio.

Payload: The data from your Lorawan Getway.

We need to pay attention to Payload. Do you remember the previously defined array Lora_data[]? Yes, Payload shows Lora_data[]. From left to right are Lora_data[0], Lora_data[1]. . . Lora_data [14]. These data are all in hexadecimal, which is not the same as our commonly used decimal. So let's make a simple hex conversion:

Click on "Decode Data", delete the original content on the right and enter "v;". Then click "Save". Refresh the page and you will see the decimal data.

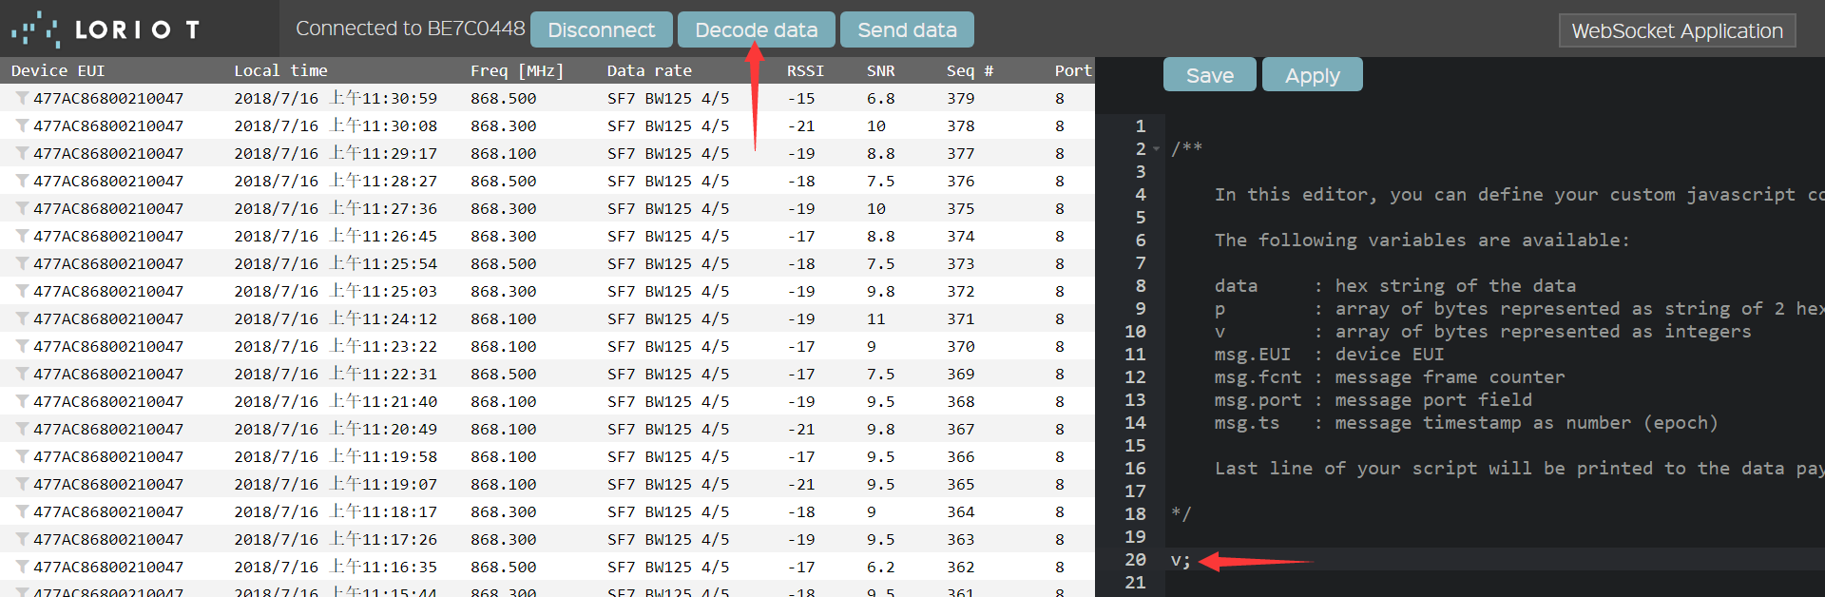
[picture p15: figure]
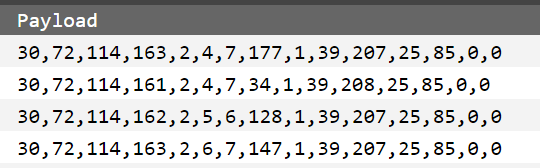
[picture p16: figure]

Ok, it looks good. And you can see the air temperature is 30 degrees Celsius and the humidity is 72%. The air is a bit hot and humid because it is raining outside.

## Make a waterproof platform for these electronic devices

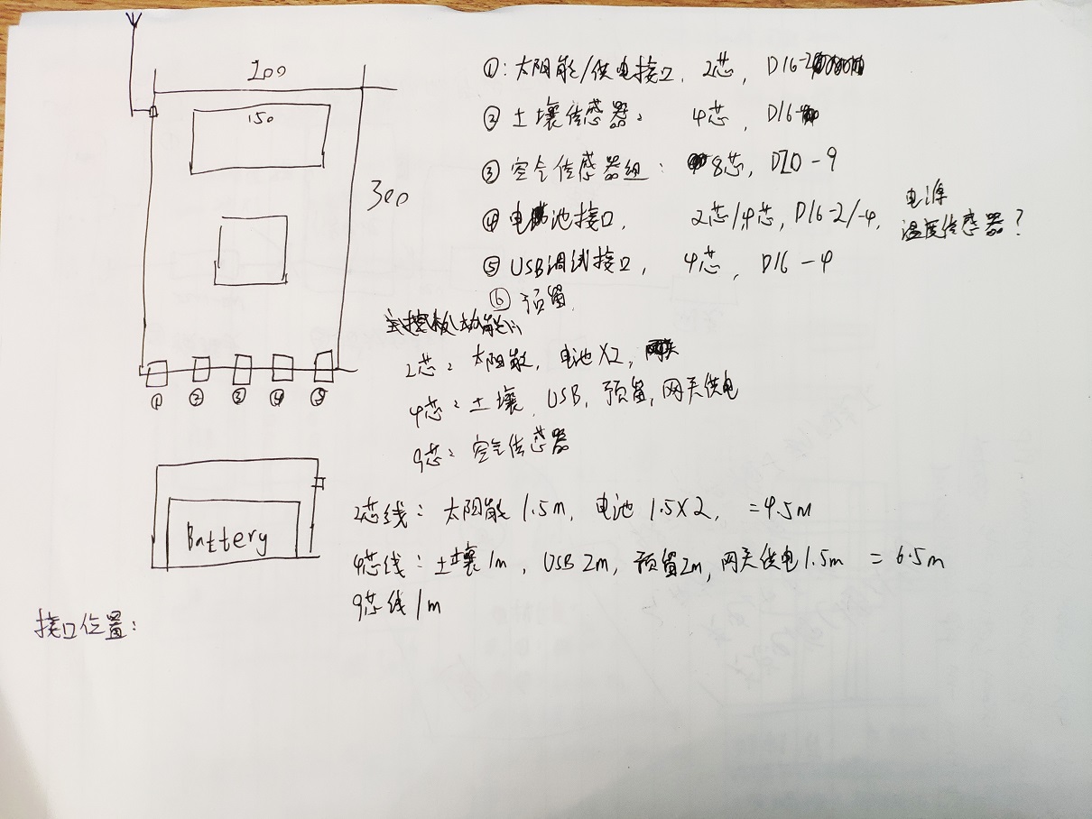
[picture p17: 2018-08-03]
V1.2 CAD/V1.2接口图.jpg

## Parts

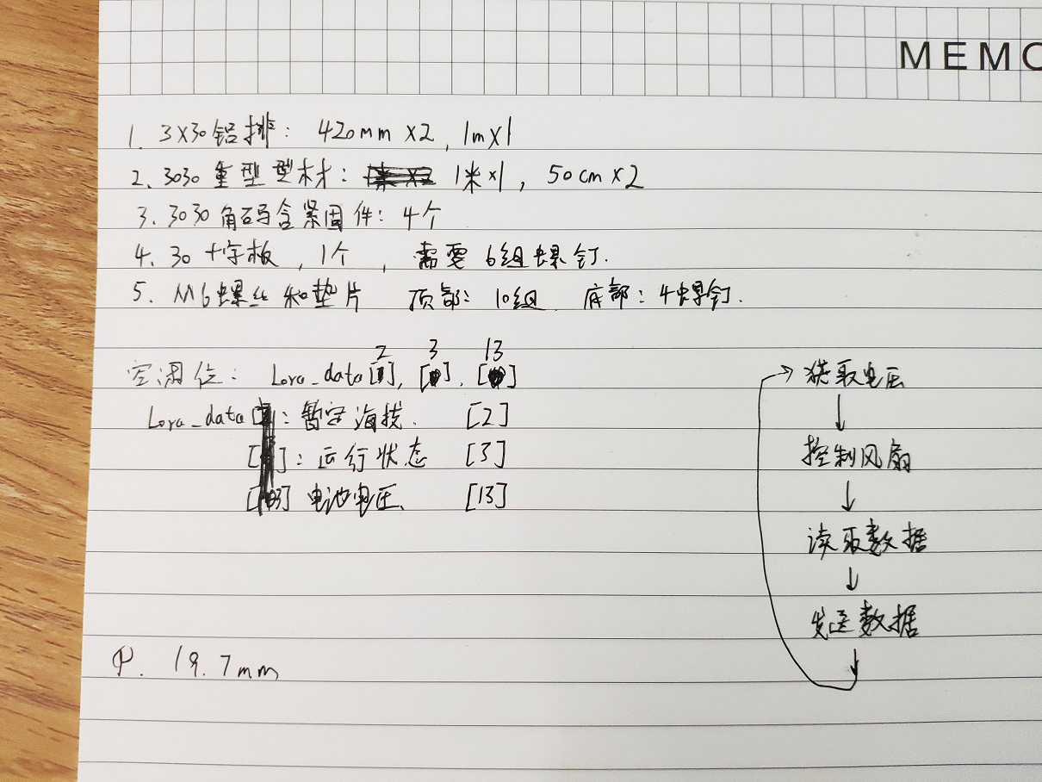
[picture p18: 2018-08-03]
V1.2 CAD/V1.2 部分机械零件清单.jpg

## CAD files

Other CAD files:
V1.2 CAD/4G ban.dwg
V1.2 CAD/fen_diaoke.dwg
V1.2 CAD/getway di ban.dwg
V1.2 CAD/chongdianyouban.dwg
V1.2 CAD/jiediandiban.dwg
V1.2 CAD/fenshan jiagao.dwg
V1.1 CAD/test.dwg
V1.1 CAD/shuban.dwg
V1.1 CAD/Getway Box.dwg
V1.1 CAD/15x15.dwg
V1.1 CAD/17x17.dwg
V1.1 CAD/getway diaoke.dwg
V1.1 CAD/lora diaoke.dwg
V1.1 CAD/13x21.dwg
V1.1 CAD/Seeeduino Lora Box.dwg
V1.1 CAD/10x10.dwg
V1.1 CAD/10x10.CATPart
V1.1 CAD/15x15.CATPart
V1.1 CAD/Getway Box.CATPart
V1.1 CAD/Part3.CATPart
V1.1 CAD/Part4.CATPart
V1.1 CAD/Seeeduino Lora Box.CATPart
V1.1 CAD/baiyechuang.CATPart
V1.1 CAD/getway board .CATPart
V1.1 CAD/seeeduino board.CATPart
V1.1 CAD/shu ban.CATPart
V1.1 CAD/test.CATPart
V1.2 CAD/300x200x160.CATPart
V1.2 CAD/4G ban.CATPart
V1.2 CAD/Part1.CATPart
V1.2 CAD/Product1.CATProduct
V1.2 CAD/chongdiantouban-zhuan.CATPart
V1.2 CAD/chongdiantouban.CATPart
V1.2 CAD/fan.CATPart
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

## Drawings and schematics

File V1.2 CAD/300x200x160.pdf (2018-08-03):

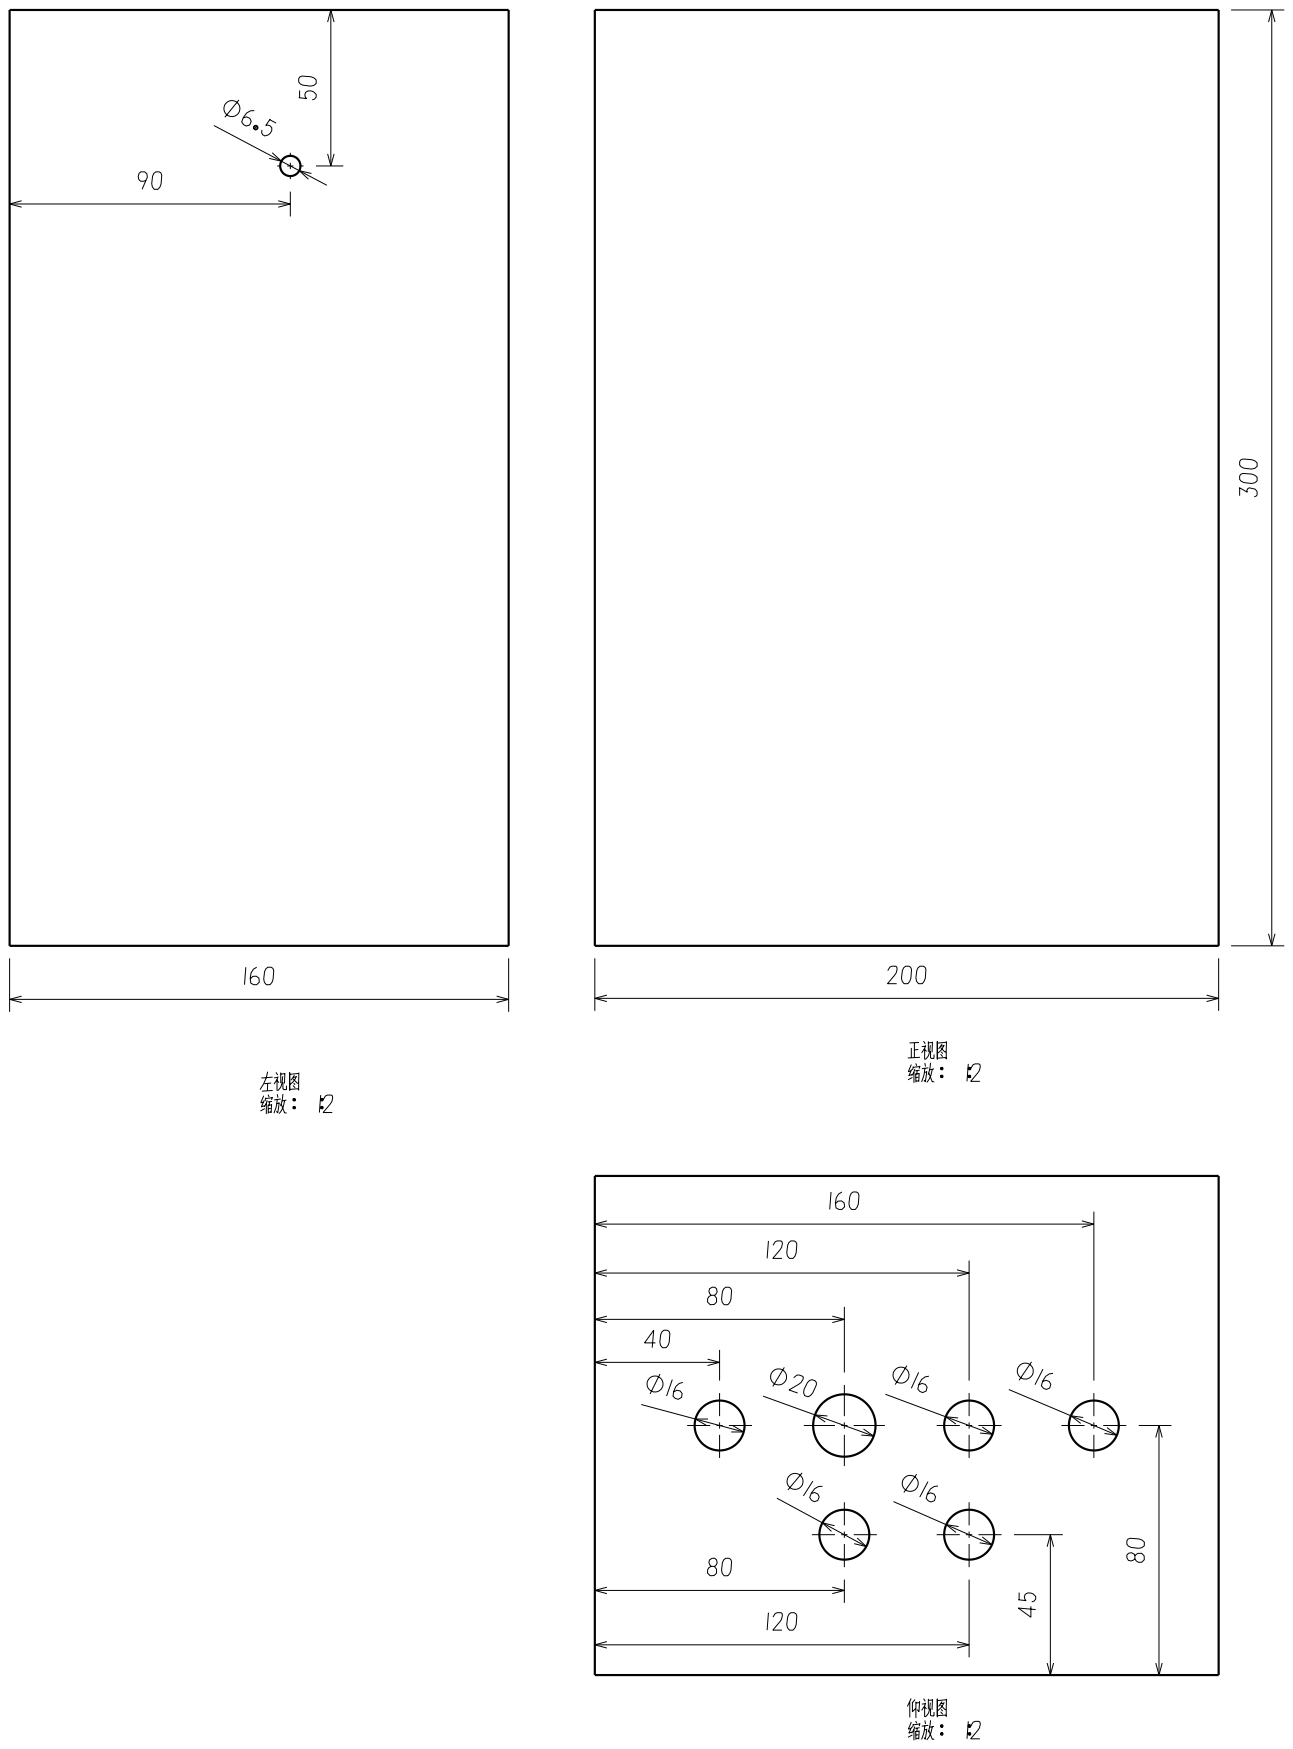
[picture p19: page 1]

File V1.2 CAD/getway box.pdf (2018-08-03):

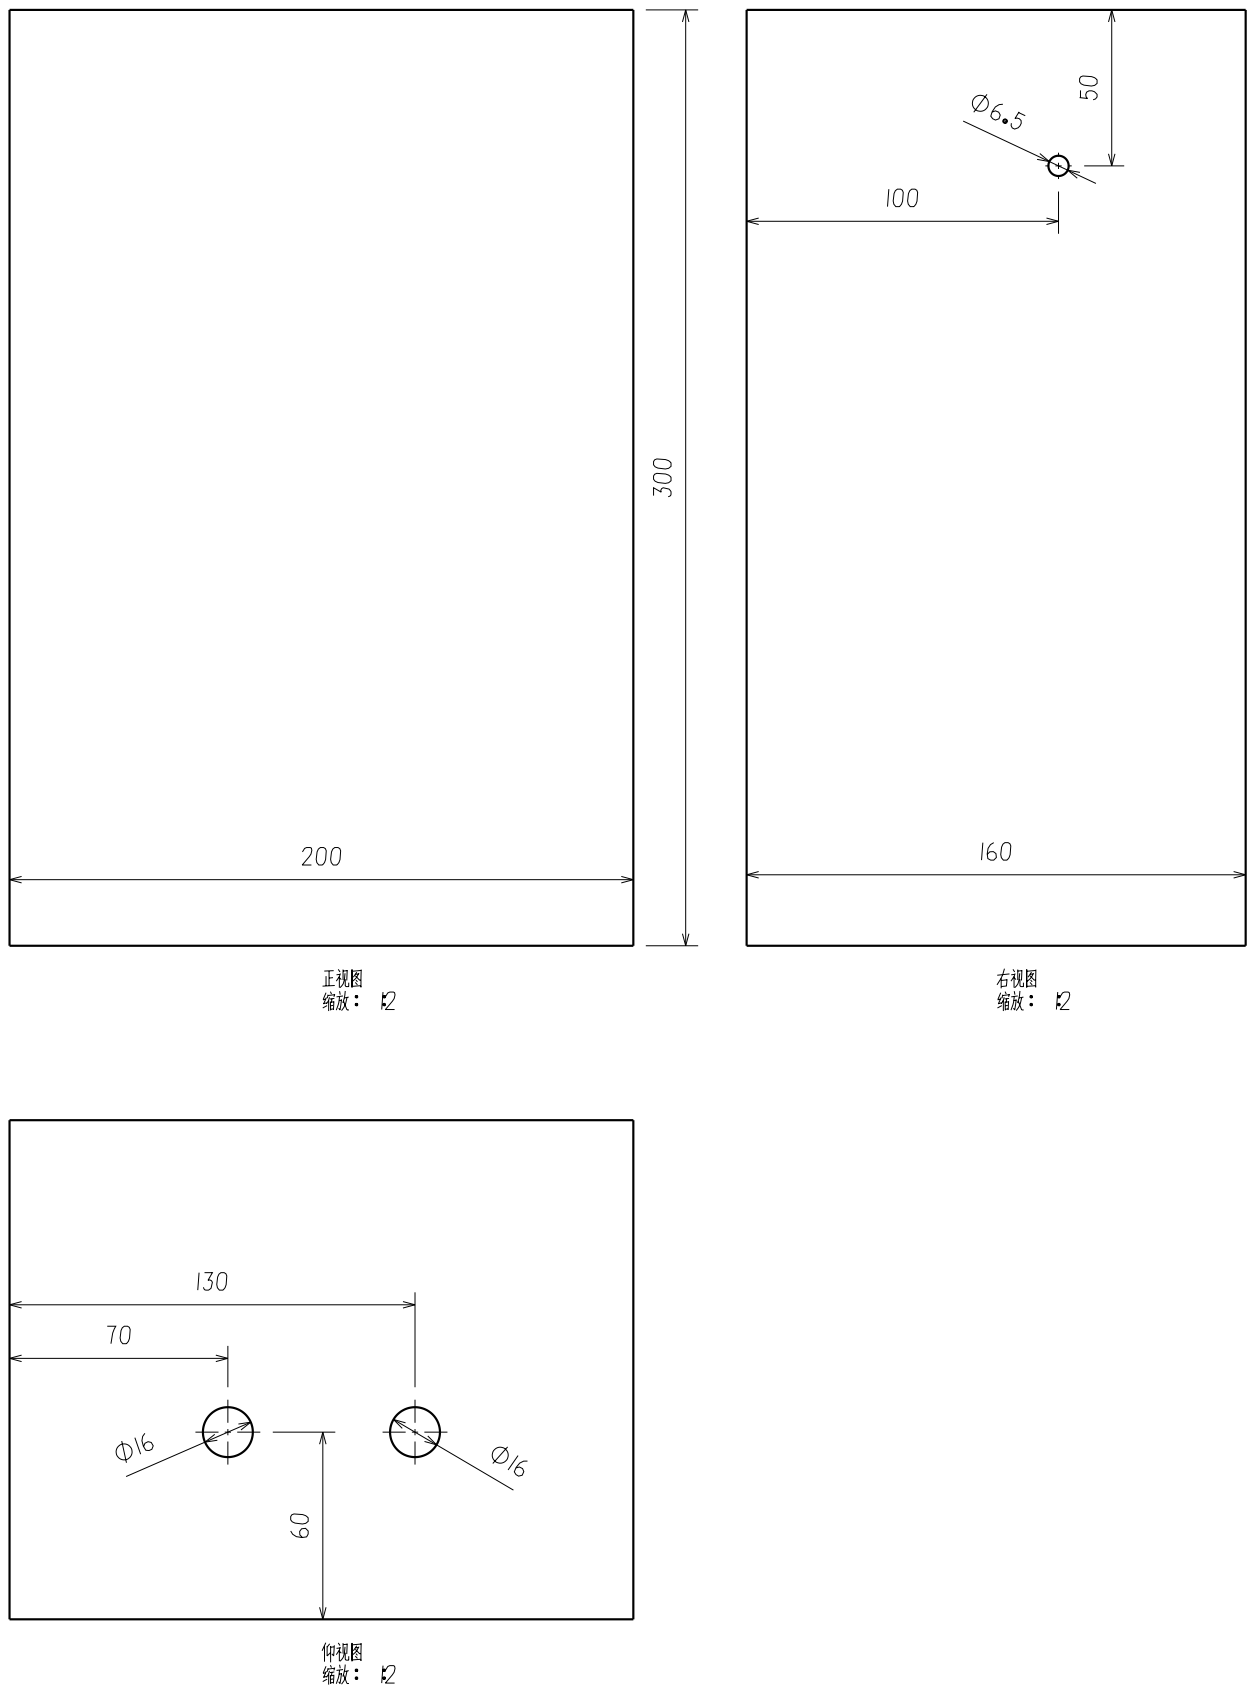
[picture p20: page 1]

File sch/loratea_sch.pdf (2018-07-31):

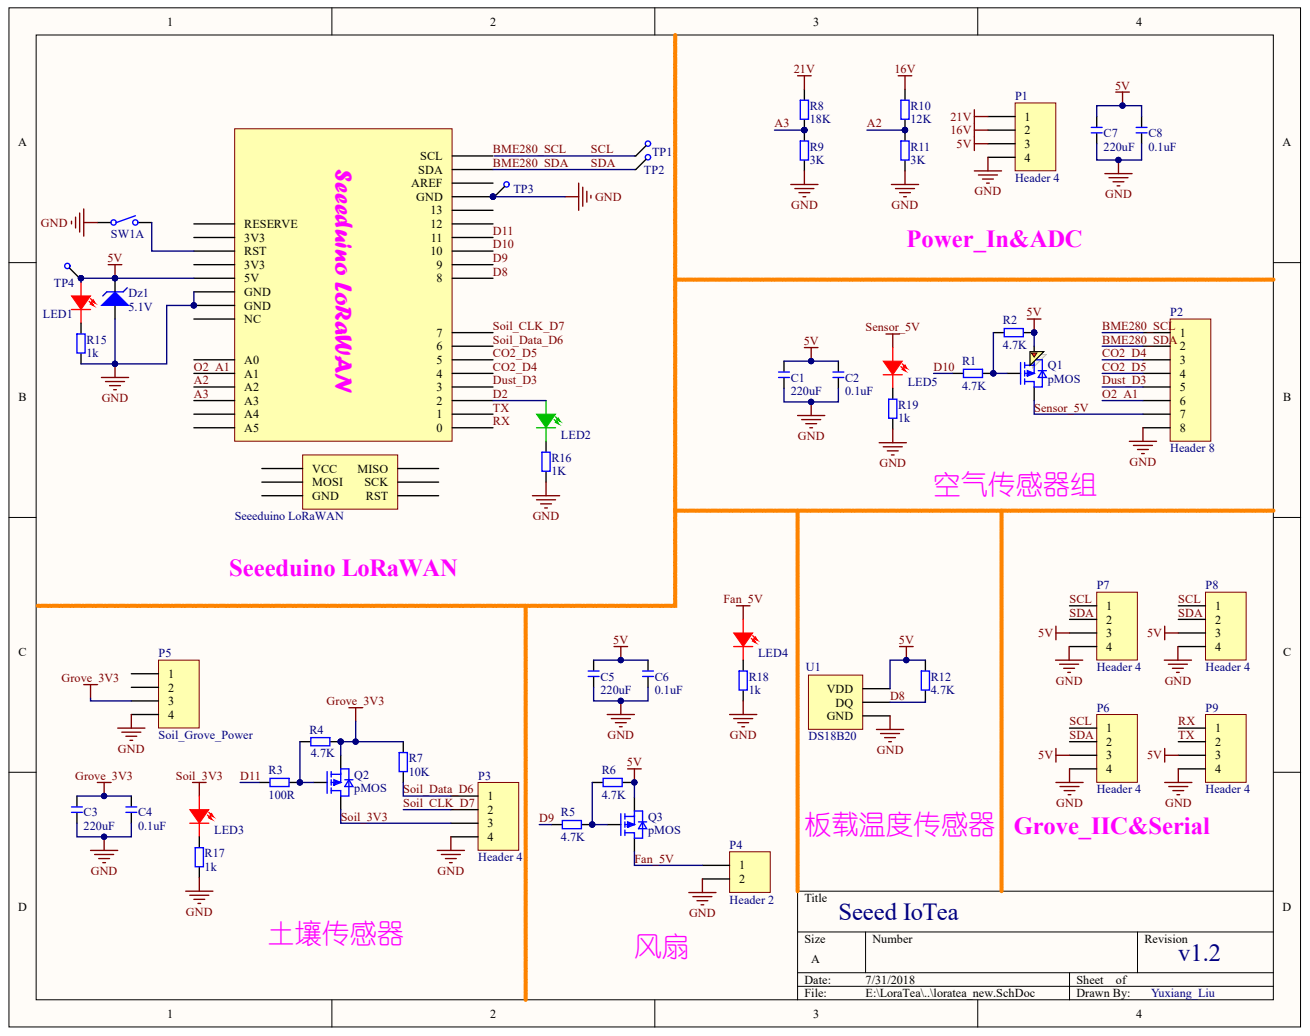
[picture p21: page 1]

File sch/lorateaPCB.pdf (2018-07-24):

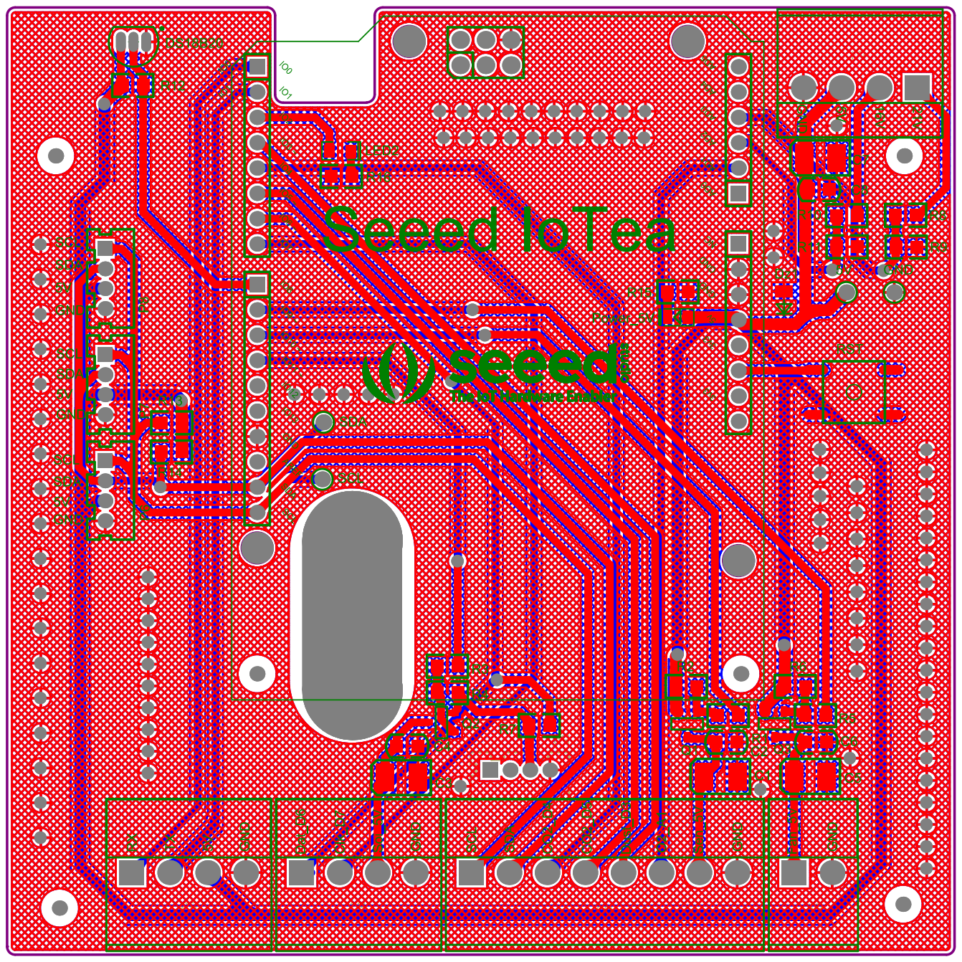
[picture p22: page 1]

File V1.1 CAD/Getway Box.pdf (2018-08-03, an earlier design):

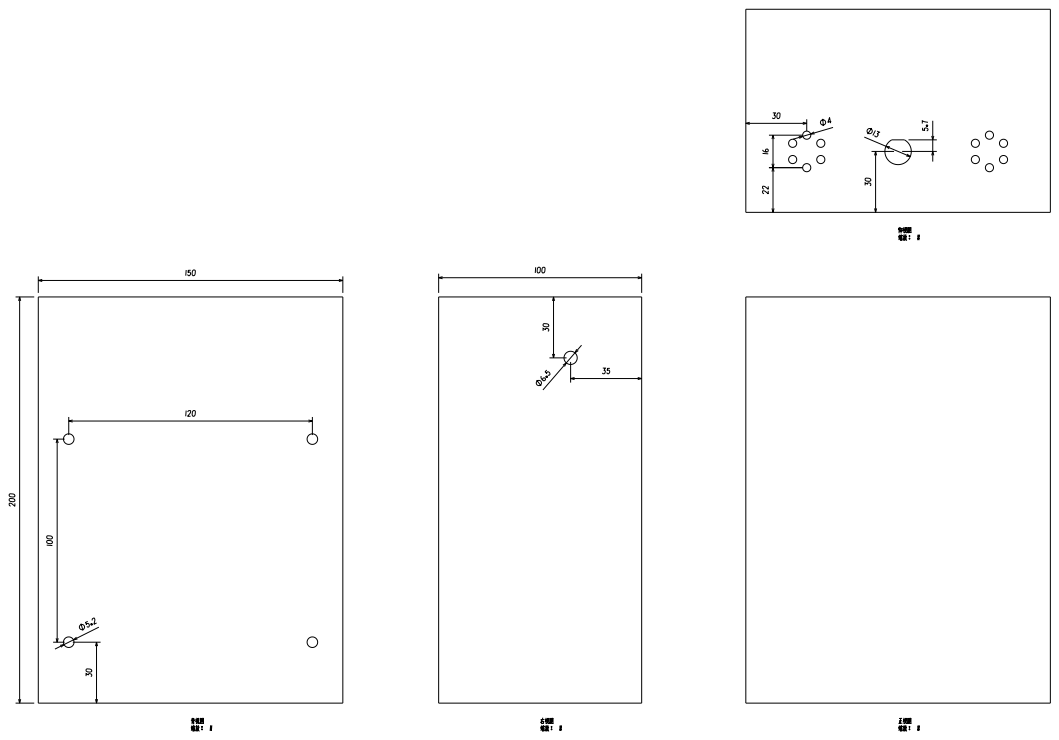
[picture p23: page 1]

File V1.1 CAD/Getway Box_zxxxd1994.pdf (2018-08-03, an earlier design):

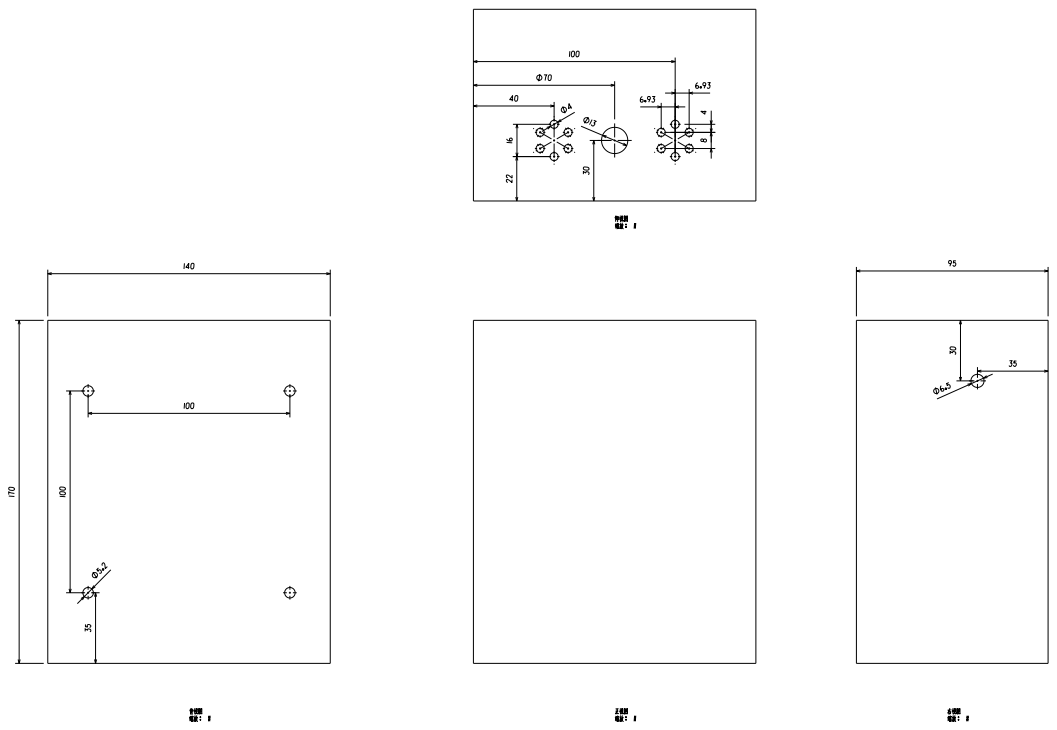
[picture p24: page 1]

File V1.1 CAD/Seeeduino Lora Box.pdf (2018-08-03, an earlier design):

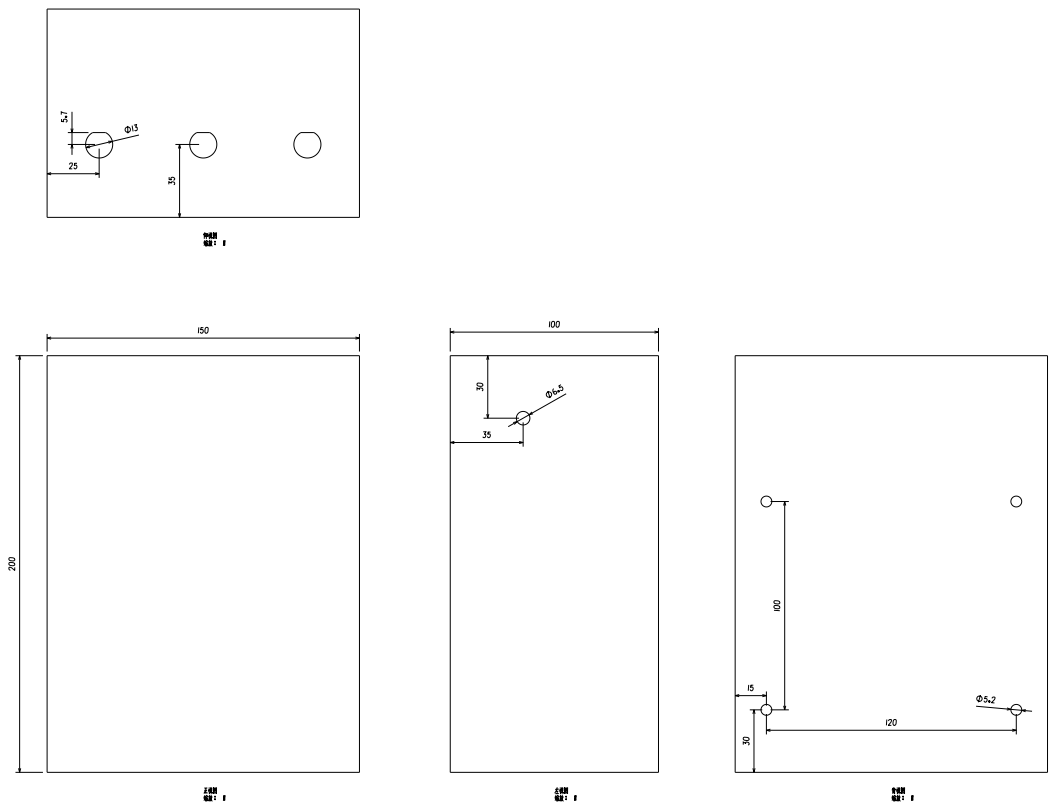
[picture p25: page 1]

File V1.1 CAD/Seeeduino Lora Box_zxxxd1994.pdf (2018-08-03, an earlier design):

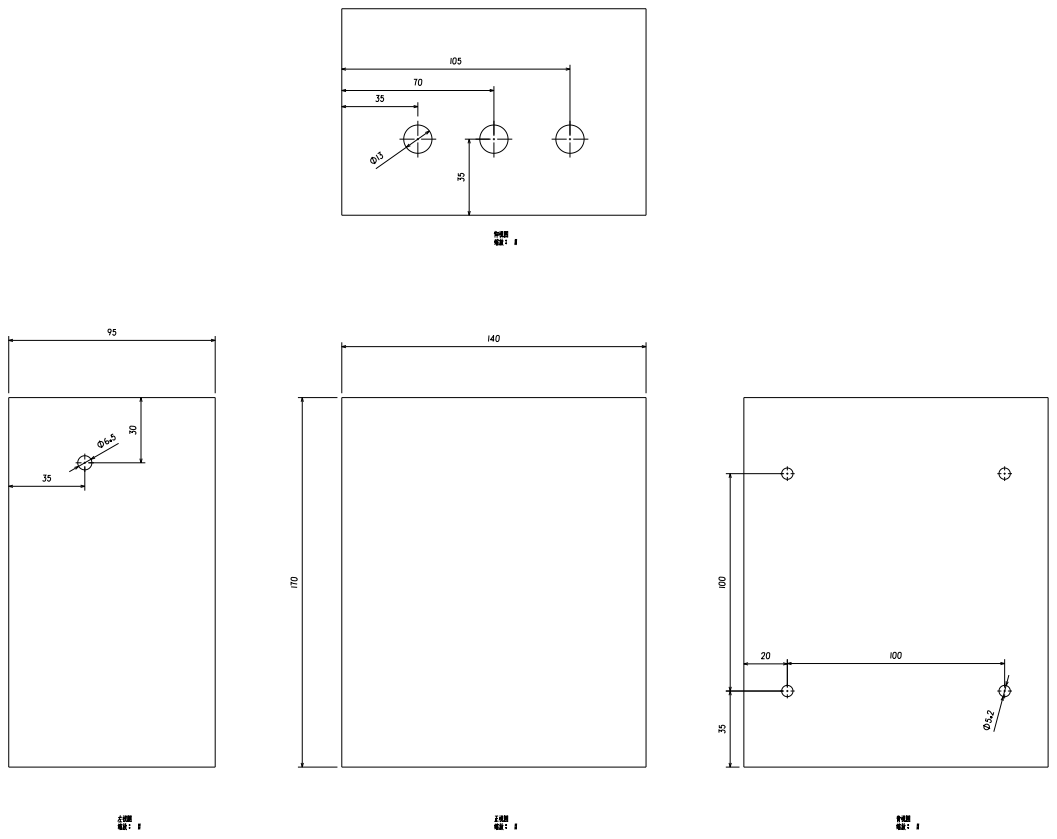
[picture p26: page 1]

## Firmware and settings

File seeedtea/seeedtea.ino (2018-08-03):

/*
Name:		seeedtea.ino
Created:	2018/4/13 14:09:27
Author:	zxd
*/

/****** 看门狗定时器：#include "Adafruit_SleepyDog.h"*********
* 使用看门狗进行自动复位
* 看门狗最长喂狗周期16秒
* 看门狗启动：Watchdog.enable(Dog_time);
* 喂狗：Watchdog.reset();
* 停止看门狗：Watchdog.disable();
**************************************************/


// the setup function runs once when you press reset or power the board
#include "Adafruit_SleepyDog.h"		//看门狗库
#include "POWER_Ctrl.h"
#include "SHT1x.h"
#include <Wire.h>
#include <string.h>
#include "Digital_Light_TSL2561.h"
#include "seeed_Lora.h"
#include <LoRaWan.h>
#include "Dust_other.h"
#include "CO2.h"
#include <SoftwareSerial.h>
#include "BME280.h"
#include <EnergySaving.h>
#include "Oxygen.h"

//宏开关，注释后会停止相应模块工作
#define LORA_RUN
#define SENSOR_RUN

//系统运行时间，用于低功耗控制
unsigned long system_time = 0;		//存储上次运行时间
#define interval_time 180			//间隔时间，秒
#define Preheat_time 30000			//Dust Sensor预热时间
#define Dog_time 16000				//看门狗复位时间，最长为16秒

#define dataPin 6 //土壤水分和温度传感器数据引脚
#define clockPin 7 //土壤水分和温度传感器时钟引脚
SHT1x sht1x(dataPin, clockPin);


#define bme280_error 0		//0000 0000
#define CO2_error 1			//0000 0001
#define dust_error 2
#define light_error 3
#define O2_error 4
#define soil_error 5

#define soil_temp_low 0
#define soil_temp_high 124
#define soil_humi_low 0
#define soil_humi_high 100
#define TSL2561_data_low 0
#define TSL2561_data_high 65535


BME280 bme280;
const unsigned char data_length = 15;
unsigned char Lora_data[15] = { 1, 2, 3, 4, 5, 6, 7, 8, 9, 10,11,12,13,0,0 };
int temp; //温度
int hum;  //湿度
int pressure; //压力
int altitude; //海拔
			  //unsigned int pressure_left;
			  //unsigned int pressure_right;
unsigned int altitude_left;
unsigned int altitude_right;
signed long TSL2561_data; //光传感器数据
int Dust_value; //灰尘数据
unsigned char o2_value;  //本次氧气数值
unsigned char last_value = 207;//上次氧气数值
float soil_temp;//土壤温度
float soil_humi;//土壤湿度

bool LED_flag = 0;

void Feed_dog(void)		//喂狗，同时闪灯
{
	Watchdog.reset();
	if (LED_flag)
		digitalWrite(LED, 0);
	else
		digitalWrite(LED, 1);
	LED_flag = !LED_flag;
}

void setup() {
	pinMode(2, OUTPUT);		//供外部单片机复位参考
	pinMode(Air_CtrlPin, OUTPUT);
	pinMode(Soil_CtrlPin, OUTPUT);
	pinMode(Dust_pin, INPUT);
	pinMode(O2_pin, INPUT);
	digitalWrite(Air_CtrlPin, 1);	//关电源
	digitalWrite(Soil_CtrlPin, 1);
	Wire.begin();
	SerialUSB.begin(9600);		//USB
	power_ctrl_init();
	CO2_init();
#ifdef LORA_RUN
	Lora_begin();	//Lora_begin();
	memset(Lora_data, 0, sizeof(Lora_data));
	Lora_send(data_length);
#endif // LORA_RUN
	Watchdog.enable(Dog_time);
	Feed_dog();		//喂狗，同时闪灯
}


// the loop function runs over and over again until power down or reset
void loop()
{
	Feed_dog();		//喂狗，同时闪灯
	bool power_state;	//1为电池有电，0为电池没电
	power_state = power_ctrl();
	SerialUSB.print("power_state = ");
	SerialUSB.println(power_state);

#ifdef SENSOR_RUN
	unsigned long time_2 = 0;
	bool time_state = 0;	//1为时间足够，可以采集数据

	if (0 == system_time)
		time_state = 1;
	else
	{
		time_2 = (millis() - system_time) / 1000;
		if (time_2 >= interval_time)
			time_state = 1;
	}
	
	SerialUSB.print("time_state = ");
	SerialUSB.println(time_state);
	if (power_state == 1 && time_state == 1)
	{
		system_time = millis();
		SerialUSB.println("Sensor power on!");
		digitalWrite(Air_CtrlPin, 0);	//开电源
		digitalWrite(Soil_CtrlPin, 0);
		delay(3000);
		Feed_dog();		//喂狗，同时闪灯
		get_AllSensorData();
		Feed_dog();		//喂狗，同时闪灯
		SerialUSB.println("Sensor power off!");
		digitalWrite(Air_CtrlPin, 1);	//关电源
		digitalWrite(Soil_CtrlPin, 1);
#ifdef LORA_RUN
		Lora_send(data_length);
		Feed_dog();		//喂狗，同时闪灯
#endif // LORA_RUN		
	}
	else
	{
		digitalWrite(Air_CtrlPin, 1);	//关电源
		digitalWrite(Soil_CtrlPin, 1);
		delay(6000);
	}
	SerialUSB.println("finish loop");
	Feed_dog();		//喂狗，同时闪灯
	delay(200);
#else
	Feed_dog();		//喂狗，同时闪灯
	delay(1000);
#endif // SENSOR_RUN
}







bool get_AllSensorData()	//获取所有传感器的数据
{
	unsigned long D_time;	//为Dust Sensor记录上电时间
	D_time = millis();
	SerialUSB.println("get_BME280_data");
	get_BME280_data();
	Feed_dog();		//喂狗，同时闪灯
	SerialUSB.println("get_CO2_data");
	get_CO2_data();		//内置喂狗
	Feed_dog();		//喂狗，同时闪灯
	SerialUSB.print("get_Light_data ");
	SerialUSB.println(get_Light_data());
	Feed_dog();		//喂狗，同时闪灯
	SerialUSB.println("get_O2_data");
	get_O2_data();
	Feed_dog();		//喂狗，同时闪灯
	SerialUSB.println("get_soil_data");
	get_soil_data();
	Feed_dog();		//喂狗，同时闪灯
	/*****************************************************************/
	//获取电压数据
	//Lora_data[13]:电压
	Lora_data[13] = get_voltage();
	Feed_dog();		//喂狗，同时闪灯
	/*****************************************************************/
	SerialUSB.println("get_Dust_data");
	while ((millis() - D_time) < Preheat_time)		//等待预热时间
	{
		delay(100);
		Feed_dog();		//喂狗，同时闪灯
	}
	get_Dust_data();
	Feed_dog();		//喂狗，同时闪灯
	SerialUSB.println("get_Dust_data OK");
	return 1;
}

void get_BME280_data()
{
	/*****************************************************************/
	//获取温湿度气压传感器数据
	//Lora_data[0]:温度,Lora_data[1]:湿度,Lora_data[2_3]:气压
	//错误代码Lora_data[14] bit0,1：error，0：no_error
	delay(2000);
	if (!bme280.init()) {
		//SerialUSB.println("bme280 init error!");
		Lora_data[14] = 1;		//错误代码1：BME280初始化失败
	}
	delay(200);
	temp = bme280.getTemperature();
	if (temp != 0)
	{
		hum = bme280.getHumidity();
		pressure = bme280.getPressure();
		altitude = bme280.calcAltitude(pressure);
		altitude_right = altitude & 0x00ff;
		altitude_left = altitude >> 8;
		Lora_data[0] = temp & 0x00ff;		//空气湿度
		Lora_data[1] = hum & 0x00ff;		//空气湿度
		Lora_data[2] = altitude_left;		//海拔高8位
		Lora_data[3] = altitude_right;		//海拔低8位
		Lora_data[14] = Lora_data[14] & (~(1 << bme280_error)); //错误位清0
		SerialUSB.print("temp = ");
		SerialUSB.println(temp);
		SerialUSB.print("hum = ");
		SerialUSB.println(hum);
		SerialUSB.print("altitude = ");
		SerialUSB.println(altitude);
	}
	else
	{
		Lora_data[0] = 0;		//空气湿度
		Lora_data[1] = 0;		//空气湿度
		Lora_data[2] = 0;		//气压高8位
		Lora_data[3] = 0;		//气压低8位
		Lora_data[14] = Lora_data[14] | (1 << bme280_error); //错误位置1
		SerialUSB.println("bme280_ERROR");
	}
	//delay(1000);
	/*****************************************************************/
}

void get_CO2_data()
{
	/*****************************************************************/
	//获取CO2传感器数据
	//Lora_data[4_5]:CO2浓度
	//错误代码Lora_data[14] bit1,1：error，0：no_error
	unsigned int CO2PPM = 0;
	CO2PPM = CO2_dataRecieve();
	if (CO2PPM != 0)
	{
		Lora_data[4] = CO2PPM >> 8;			//CO2高8位
		Lora_data[5] = CO2PPM & 0x00ff;		//CO2低8位
		Lora_data[14] = Lora_data[14] & (~(1 << CO2_error)); //错误位清0
		SerialUSB.print("CO2PPM = ");
		SerialUSB.println(CO2PPM);
	}
	else
	{
		Lora_data[4] = 0;
		Lora_data[5] = 0;
		Lora_data[14] = Lora_data[14] | (1 << CO2_error); //错误位置1
		SerialUSB.println("CO2_ERROR");
	}
	delay(100);
	/*****************************************************************/
}

void get_Dust_data()
{
	/*****************************************************************/
	//获取灰尘传感器数据
	//Lora_data[6_7]:灰尘
	//错误代码Lora_data[14] bit2,1：error，0：no_error
	Dust_value = Dust_concentration();
	if (Dust_value != 0)
	{
		/*SerialUSB.print("Dust_value=");
		SerialUSB.println(Dust_value);*/

		Lora_data[6] = Dust_value >> 8;
		Lora_data[7] = Dust_value & 0x00ff;
		Lora_data[14] = Lora_data[14] & (~(1 << dust_error)); //错误位清0
		SerialUSB.print("Dust_value = ");
		SerialUSB.println(Dust_value);
	}
	else
	{
		Lora_data[6] = 0;
		Lora_data[7] = 0;
		Lora_data[14] = Lora_data[14] | (1 << dust_error); //错误位置1
		SerialUSB.println("dust_ERROR");
	}
	delay(1000);
	/*****************************************************************/
}

int get_Light_data()
{
	/*****************************************************************/
	//获取光照传感器数据
	//Lora_data[8_9]:光照
	//错误代码Lora_data[14] bit3,1：error，0：no_error
	unsigned long sum = 0;
	char x = 0;
	delay(2000);
	if (TSL2561.init() == 0)
	{
		Lora_data[8] = 0;//光照高8位
		Lora_data[9] = 0;//光照低8位
		Lora_data[14] = Lora_data[14] | (1 << light_error); //错误位置1
		SerialUSB.println();
		SerialUSB.println("light_ERROR, can not find the sensor");
		return 0;
	}
	delay(500);
	for (int i = 10; i > 0; i--)
	{
		TSL2561_data = TSL2561.readVisibleLux();
		if (TSL2561_data >= 0)//判断光照是否在正常范围
		{
			x++;
			sum = sum + TSL2561_data;
		}
		delay(500);
	}
	if (x != 0)
	{
		TSL2561_data = sum / x;
		Lora_data[8] = (unsigned  char)((TSL2561_data >> 8) & 0xff);//光照高8位
		Lora_data[9] = (unsigned  char)(TSL2561_data & 0x00ff);		//光照低8位
		Lora_data[14] = Lora_data[14] & (~(1 << light_error)); //错误位清0
		SerialUSB.print("TSL2561_data = ");
		SerialUSB.println(TSL2561_data);
	}
	else
	{
		TSL2561_data = 0;
		Lora_data[8] = 0;//光照高8位
		Lora_data[9] = 0;//光照低8位
		Lora_data[14] = Lora_data[14] | (1 << light_error); //错误位置1
		SerialUSB.println("light_ERROR");
	}
	//SerialUSB.println(TSL2561.readVisibleLux());
	/*if ((TSL2561_data >= TSL2561_data_low) && (TSL2561_data <= TSL2561_data_high))//判断光照是否在正常范围
	{
		Lora_data[8] = (unsigned  char)((TSL2561_data >> 8) & 0xff);//光照高8位
		Lora_data[9] = (unsigned  char)(TSL2561_data & 0x00ff);		//光照低8位
		Lora_data[14] = Lora_data[14] & (~(1 << light_error)); //错误位清0
	}
	else
	{
		Lora_data[8] = 0;//光照高8位
		Lora_data[9] = 0;//光照低8位
		Lora_data[14] = Lora_data[14] | (1 << light_error); //错误位置1
		SerialUSB.println("light_ERROR");
		SerialUSB.println(TSL2561_data);
		SerialUSB.println();
	}*/
	//delay(1000);
	return TSL2561_data;
	/*****************************************************************/
}

void get_O2_data()
{
	/*****************************************************************/
	//获取氧气传感器数据
	//Lora_data[10]:氧气
	//错误代码Lora_data[14] bit4,1：error，0：no_error
	/*以下为氧气传感器的不正确时的数据暂行显示策略*/
	//   o2_value = (unsigned char)random(205, 210);
	//if (abs((o2_value-last_value)) <= 1)
	//{
	//	Lora_data[10] = o2_value;//氧气数据
	//	last_value = o2_value;
	//	Lora_data[14] = Lora_data[14] & (~(1 << O2_error)); //错误位清0
	//}



	/*以下为氧气数据正确时的代码*/
	o2_value = (unsigned char)O2_value();
	if ((o2_value >= 170) && (o2_value <= 215))//判断O2是否在正常范围
	{
		Lora_data[10] = o2_value;//氧气数据
		Lora_data[14] = Lora_data[14] & (~(1 << O2_error)); //错误位清0
		SerialUSB.print("o2_value = ");
		SerialUSB.println(o2_value);
	}
	else
	{
		Lora_data[10] = 0;
		O2_init_flag = 0; //重新校准O2传感器
		Lora_data[14] = Lora_data[14] | (1 << O2_error); //错误位置1
		SerialUSB.print("O2_ERROR");
		SerialUSB.println();
	}
	delay(1000);
	/*****************************************************************/
}

void get_soil_data()
{
	/*****************************************************************/
	//获取土壤温湿度传感器数据
	//Lora_data[11]:温度 Lora_data[12]:湿度
	//错误代码Lora_data[14] bit5,1：error，0：no_error
	soil_temp = sht1x.readTemperatureC();

	soil_humi = sht1x.readHumidity();
	SerialUSB.println();
	SerialUSB.println();
	SerialUSB.println(soil_temp, DEC);
	SerialUSB.println(soil_humi, DEC);
	if (((soil_temp >= soil_temp_low) && (soil_temp <= soil_temp_high)) && ((soil_humi >= soil_humi_low) && (soil_humi <= soil_humi_high))) //判断温湿度数据范围是否正确
	{
		Lora_data[11] = (unsigned char)(soil_temp);
		Lora_data[12] = (unsigned char)(soil_humi);
		Lora_data[14] = Lora_data[14] & (~(1 << soil_error)); //错误位清0
		SerialUSB.print("soil_temp = ");
		SerialUSB.println(soil_temp);
		SerialUSB.print("soil_humi = ");
		SerialUSB.println(soil_humi);
	}
	else
	{
		Lora_data[11] = 0;
		Lora_data[12] = 0;
		Lora_data[14] = Lora_data[14] | (1 << soil_error); //错误位置1
		SerialUSB.println("soil_ERROR");
		SerialUSB.println((unsigned char)soil_temp);
		SerialUSB.println((unsigned char)soil_humi);
	}
	delay(2000);
	/*****************************************************************/
}

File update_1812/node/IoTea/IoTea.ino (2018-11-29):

/*
 * IoTea.ino
 * Main file of project IoTea
 * NOTICE: setup() method and loop() method are packaged in Application class, 
 *		   see Application.h and Application.cpp
 *
 * Copyright (c) 2018 seeed technology inc.
 * Author		: Lets Blu
 * Created Time	: Oct 2018
 * Modified Time:
 *
 * The MIT License (MIT)
 *
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
 * THE SOFTWARE IS PROVIDED "AS IS", WITHOUT WARRANTY OF ANY KIND, EXPRESS OR
 * IMPLIED, INCLUDING BUT NOT LIMITED TO THE WARRANTIES OF MERCHANTABILITY,
 * FITNESS FOR A PARTICULAR PURPOSE AND NONINFRINGEMENT. IN NO EVENT SHALL THE
 * AUTHORS OR COPYRIGHT HOLDERS BE LIABLE FOR ANY CLAIM, DAMAGES OR OTHER
 * LIABILITY, WHETHER IN AN ACTION OF CONTRACT, TORT OR OTHERWISE, ARISING FROM,
 * OUT OF OR IN CONNECTION WITH THE SOFTWARE OR THE USE OR OTHER DEALINGS IN
 * THE SOFTWARE.
 */

#include "application\application.h"
#include "application\interface\IApplication.h"

using namespace application;
using namespace application::interface;

IApplication * app = Application::getInstance();

void setup() {
	SerialUSB.begin(115200);
	while (!SerialUSB);

	app->setup();
}

void loop() {
	app->loop();
}

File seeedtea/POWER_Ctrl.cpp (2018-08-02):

// Author: zxd    Date:2018/07/23
// 本库文件用来进行电源管理和温度控制
// 16V分压电阻：3K和12K       23V分压电阻：3K和18K


//温控风扇调试。如果装箱就注释掉。
#define FAN_ON

#include "POWER_Ctrl.h"
#include "OneWire.h"			//1线式通讯协议 库文件
#include "DallasTemperature.h"	//DS18B20 库文件

//电压系数，被放大了10倍
#define Battery_coefficient 0.159864	//ADC读数乘以这个系数就是电池电压
#define Solar_coefficient   0.22559	//ADC读数乘以这个系数就是太阳能电压

//风扇开始运行温度和光强
#define Fan_start_temp 45
#define Fan_start_light 500


//电压都被放大10倍，例如126表示12.6V
uint8_t Battery_voltage;
uint8_t Solar_voltage;

/****************** DS18B20相关 ***************************/
#define Slower_Mode		//慢速模式获取温度。注释掉即为快速模式

OneWire oneWire(DS18B20_pin);
DallasTemperature sensors(&oneWire);
DeviceAddress insideThermometer;

void printAddress(DeviceAddress deviceAddress)
{
	for (uint8_t i = 0; i < 8; i++)
	{
		if (deviceAddress[i] < 16) SerialUSB.print("0");
		SerialUSB.print(deviceAddress[i], HEX);
	}
}

/*****************************************************/

bool power_ctrl_init()		//初始化温度和电压读取。返回1为正常
{
	pinMode(Solar_pin, INPUT);
	pinMode(Battery_pin, INPUT);
	pinMode(Fan_pin, OUTPUT);
	Fan(1);
	SerialUSB.print("Locating devices...");
	sensors.begin();
	SerialUSB.print("Found ");
	SerialUSB.print(sensors.getDeviceCount(), DEC);
	SerialUSB.println(" devices.");
	delay(1000);
	Fan(0);
	if (!sensors.getAddress(insideThermometer, 0))
	{
		SerialUSB.println("Unable to find address for Device 0");
		return 0;
	}
	else
		return 1;
}

int get_box_temperature()	//获取盒子内部温度
{
	int box_temp;
	sensors.requestTemperatures();
#ifdef Slower_Mode
	// method 1 - slower
	box_temp = sensors.getTempC(insideThermometer);
	
#else
	// method 2 - faster
	float tempC = sensors.getTempC(insideThermometer);
#endif

	if (box_temp > -50 && box_temp < 100)
	{
		SerialUSB.print("temp = ");
		SerialUSB.println(box_temp);
		return box_temp;
	}
	else
		return 0xffff;
}

uint8_t get_voltage()	//返回电池电压值，已放大10倍
{
	uint16_t B_vol = 0;
	uint16_t S_vol = 0;
	for (uint8_t i = 16; i > 0; i--)
	{
		B_vol = B_vol + analogRead(Battery_pin);
		S_vol = S_vol + analogRead(Solar_pin);
		delay(20);
	}
	//SerialUSB.print("analogRead = ");
	//SerialUSB.println(analogRead(Battery_pin));
	if (B_vol < 16384) {		//16384 = 1024 * 16
		Battery_voltage = (B_vol >> 4) * Battery_coefficient;
	}
	else
	{
		Battery_voltage = 255;
	}
	
	if (S_vol < 16384)
	{
		Solar_voltage = (S_vol >> 4) * Solar_coefficient;
	}
	else
	{
		Solar_voltage = 255;
	}
	SerialUSB.print("battery = ");
	SerialUSB.println(Battery_voltage);
	return Battery_voltage;
}


/*************************************** 
 * bool power_ctrl()控制风扇和决策传感器电源开关
 * 返回值：1为允许打开传感器电源。0为不允许。
 * 输入参数：无
 ****************************************/
void Fan(bool Fan_state)	//1为开风扇
{
	if (Fan_state) {
		digitalWrite(Fan_pin, 0);	//开风扇
	}
	else {
		digitalWrite(Fan_pin, 1);
	}	
}

bool power_ctrl()	//1为电池有电，0为电池没电
{
	int box_temp = 0;		//箱子温度
	//int light = 0;			//光线强度
	bool power_state = 0;	//1为电池有电，0为电池没电
	if (box_temp == 0xff)
		box_temp = 0;
	get_voltage();
	Fan(0);
#ifdef FAN_ON
	Battery_voltage = 127;
#endif // FAN_ON
	if (255 != Battery_voltage)
	{
		if (115 < Battery_voltage)
		{
			power_state = 1;
			if (TSL2561_data >= Fan_start_light)
			{
				if (box_temp >= Fan_start_temp)
				{
					Fan(1);
				}
			}
		}
		else
		{
			power_state = 0;
		}
	}
	else
	{
		power_state = 0;
	}
	return power_state;
}

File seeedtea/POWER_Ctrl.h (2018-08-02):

// POWER_Ctrl.h

#ifndef _POWER_CTRL_h
#define _POWER_CTRL_h

#if defined(ARDUINO) && ARDUINO >= 100
	#include "arduino.h"
#else
	#include "WProgram.h"
#endif

#define LED 2
#define DS18B20_pin 8
#define Solar_pin A3
#define Battery_pin A2
#define Fan_pin 9
//电源控制引脚，低开高关
#define Air_CtrlPin 10
#define Soil_CtrlPin 11
extern signed long TSL2561_data;	//光传感器数据
void Fan(bool Fan_state);	//1为开风扇
bool power_ctrl_init();		//初始化温度和电压读取。返回1为正常
int get_box_temperature();	//返回盒子的温度
uint8_t get_voltage();		//返回电池电压值，已放大10倍
bool power_ctrl();			//1为电池有电，0为电池没电
int get_Light_data();		//获取光线强度，辅助判断风扇开关

#endif

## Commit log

2018-07-23 cread files
    [PcbLib1.PcbLib, Schlib1.SchLib, loratea.PcbDoc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]
2018-07-24 add DS18B20 and power control
2018-07-27 Fixed issues with CO2 and I2C sensors
    [CO2.cpp, POWER_Ctrl.cpp, POWER_Ctrl.h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]
2018-07-31 The light sensor acquisition method is optimized and an external hardware reset function is added.
    [POWER_Ctrl.cpp, seeedtea.ino]
2018-07-31 update readme.md and sch files
    [loratea_new.SchDoc]
2018-08-01 add some old version code, add external MCU Autu Reset code, update code
    [Auto_Reset.ino, POWER_Ctrl.cpp, POWER_Ctrl.h]
2018-08-02 add watchdog timer
2018-08-03 Added some documents and CAD files
    [10x10.CATPart, 10x10.dwg, 13x21.dwg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]
